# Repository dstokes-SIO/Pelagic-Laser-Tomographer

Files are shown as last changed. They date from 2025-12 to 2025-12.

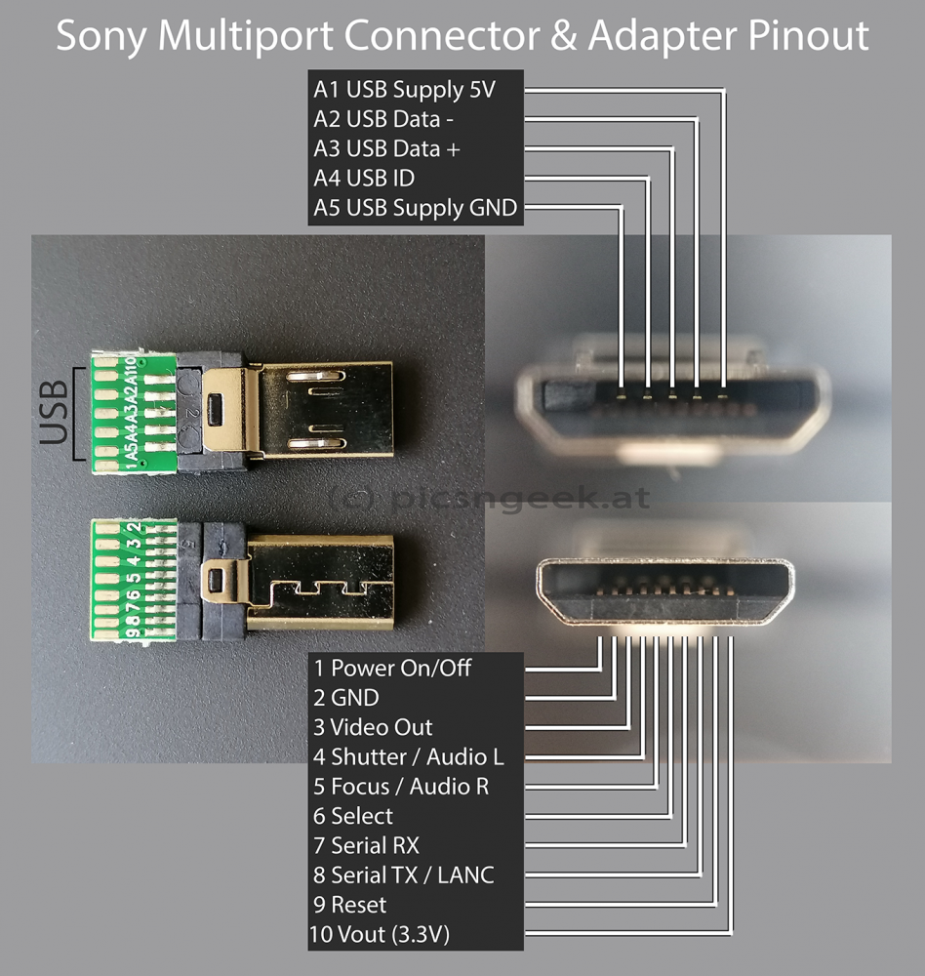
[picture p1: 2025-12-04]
Misc Hardware/Sony-Multiport-Connector-and-Adapter-Pinout-50.png

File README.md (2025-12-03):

[PLT_Processing_User_Guide.md](https://github.com/user-attachments/files/23918088/PLT_Processing_User_Guide.md)
# **PLT Processing User Guide**

## **1. Introduction**

This document describes the processing workflow for the Pelagic Laser Tomographer (PLT) dataset.  
The goal of the pipeline is to convert raw Sony ARW image sequences and associated depth logs into cleaned, standardized **dot table CSV files** for each drop.

The PLT processing pipeline is modular and consists of the following components:

- **Raw data (ARW images + CSV log)**
- **GenerateRunDrops.py** — identifies drops and organizes input files
- **RunPLTFilter.py** — stages images, runs the C++ `pltfilter` algorithm, and produces output dot files
- **Concatenate outputs** — produces `AllDots.csv` for each drop

This guide explains how to run each stage, the required directory structure, and how to interpret the resulting files.

---

## **2. Processing Pipeline Overview**

The system processes a PLT “run” (e.g., `data_50`) consisting of:

- A raw CSV log file: `data_50.csv` generated during PLT operations
- A set of raw ARW images containing several drops (drops = depth cast of PLT from winch or hand held)

The processing steps are:

1. **GenerateRunDrops.py**
   - Reads the raw images
   - Reads the raw log
   - Detects drops and isolates them
   - Produces:
     - One folder per drop
     - `images_fullpath.txt`
     - `drop_metadata.yaml`

2. **RunPLTFilter.py**
   - Reads each drop folder
   - Symlinks all images for the drop into a sequentially numbered directory
   - Cleans the log file (standardizes depth column name)
   - Constructs a `pltfilter` command based on `plt_config.yaml`
   - Calls the C++ `pltfilter` binary
   - Produces:
     - `DotsPerImage/*.dots.csv`
     - Summary histogram files
     - `AllDots.csv`

3. **Downstream analysis** (not covered here)
   - Users may apply their own scripts for density, depth structure, or cross-drop comparison.

---

## **3. Directory Structure**

A typical PLT working directory is organized as follows:

```
PLT/
  plt_config.yaml
  GenerateRunDrops.py
  RunPLTFilter.py
  PLTfilter/
    src/pltfilter
    RunTemplate/Mask.tiff
  drops/
    data_50/
      Drop01/
        images_fullpath.txt
        drop_metadata.yaml
        DropImages/
        Results/
  raw_data_05262023/
    data_50.csv
    ARW image folders
```

Key directories:

- **PLTfilter/**  
  Contains the compiled `pltfilter` executable and mask file.

- **drops/**  
  Contains per-run and per-drop processing outputs.

- **raw_data/**  
  Contains raw ARW image sets and raw log files.

---

## **4. Configuration File: `plt_config.yaml`**

All path definitions and `pltfilter` parameters live in `plt_config.yaml`.  
Important sections are:

### **4.1 paths**
```yaml
paths:
  drop_root: "/path/to/PLT/drops"
  data_file: "/path/to/raw_data/data_50.csv"
  raw_images_root: "/path/to/raw_images"
```

- `drop_root`: Parent folder under which drop folders will be created  
- `data_file`: Raw CSV log for the run  
- `raw_images_root`: Root folder containing ARW images

### **4.2 pltfilter**
Defines how `RunPLTFilter.py` constructs the C++ `pltfilter` command.

Key fields:

```yaml
pltfilter:
  binary: "/path/to/PLTfilter/src/pltfilter"
  mask_file: "/path/to/Mask.tiff"
  median_window: 3
  adaptive_threshold_window: 31
  adaptive_threshold_bias: -9
  dilation_count: 1
  min_dot_radius: 1
  max_dot_radius: 10
  min_dot_area: 1
  max_dot_area: 100
  false_z_spacing: 25.0
  pixels_per_cm: 77.165
  depth_histogram_bucket_width: 0.1
  save_dots: true
```

---

## **5. Running the Pipeline**

### **5.1 Step 1 — Prepare Raw Data**

Ensure that:

- The raw CSV log (e.g., `data_50.csv`) is located where `plt_config.yaml` points.
- ARW image folders are accessible.
- The directory structure is consistent with `GenerateRunDrops.py`.

No additional formatting of raw logs is required.

---

### **5.2 Step 2 — Identify Drops**

To process a run (e.g., run number 50):

```python
runfile("GenerateRunDrops.py", args="50", wdir="...")
```

This script:

- Reads the raw ARW images & timestamps
- Selects frames belonging to each drop
- Creates a directory for each drop:

```
drops/data_50/Drop01
drops/data_50/Drop02
...
```

Each drop folder contains:

- `images_fullpath.txt` — list of ARW file paths  
- `drop_metadata.yaml` — includes:
  - `drop_id`
  - `data_file`
  - `start_idx` (first log row for this drop)

This stage must be run before filtering.

---

### **5.3 Step 3 — Run PLT Filter**

To process all drops in a run:

```python
runfile("RunPLTFilter.py", args="50", wdir="...")
```

The script performs:

1. **Log cleaning**
   - Standardizes the “depth” column name so the C++ code recognizes it.

2. **Symlink image staging**
   - All ARW files for the drop are placed into:

     ```
     DropImages/Drop01_data_50/
       PLT000001.ARW
       PLT000002.ARW
       ...
     ```

3. **Calls the C++ `pltfilter` binary**
   - Uses parameters from the YAML file
   - Writes output to:

     ```
     Results/
       DotsPerImage/
       AllDots.csv
       DotsRadiusHistogram.csv
       DotsAreaHistogram.csv
       DotsDepthHistogram.csv
     ```

Progress and command-line details print to the console.

---

### **5.4 Step 4 — Inspect Output**

Inside each drop’s `Results/` folder:

#### **AllDots.csv**
Combined dot detections for all frames in the drop.  
Columns include:

- X-Pixels  
- Y-Pixels  
- Area  
- Radius  
- Frame number  
- Depth (if logged)

#### **DotsPerImage/**
Individual dot detections per frame.

#### **Histogram files**
Summaries of:

- Dot radii  
- Dot areas  
- Dot depth distribution

---

## **6. Troubleshooting**

### **6.1 pltfilter: column not found: Depth**
Cause: Raw log contains nonstandard column header (e.g., `depth (m)` or `Depth (m)`).

Solution:  
`RunPLTFilter.py` automatically cleans logs.  
Check for:

```
output/data_XX_clean_for_pltfilter.csv
```

Make sure the cleaned file contains a column named exactly:

```
Depth
```

---

### **6.2 pltfilter not found**
Ensure the YAML contains:

```yaml
pltfilter:
  binary: "/Users/.../PLTfilter/src/pltfilter"
```

---

### **6.3 Missing Mask.tiff**
Verify:

```yaml
mask_file: "/Users/.../PLTfilter/RunTemplate/Mask.tiff"
```

---

### **6.4 No DotsPerImage files generated**
Possible causes:

- Mask cropping out entire frame  
- Wrong threshold settings  
- Bad exposure or blank images

Try lowering threshold bias or disabling adaptive thresholding.

---

### **6.5 ARW files not found**
Check the content of:

```
drops/data_XX/DropNN/images_fullpath.txt
```

Paths must be absolute or resolvable.

---

## **7. Notes on Extending the Pipeline**

Advanced users may wish to:

- Adjust detection thresholds in YAML  
- Add new metadata fields  
- Replace `pltfilter` with a GPU version  
- Implement Python-based dot detectors  
- Export PLT dot clouds to MATLAB or NumPy arrays  
- Add automatic QA/QC after filtering  

This guide covers only the canonical workflow.

---

## **8. Summary**

This user guide provides the minimal, operational recipe for running the full PLT processing pipeline:

1. Configure paths in `plt_config.yaml`  
2. Generate drop folders using `GenerateRunDrops.py`  
3. Run filtering using `RunPLTFilter.py`  
4. Inspect `Results/AllDots.csv` and summary files

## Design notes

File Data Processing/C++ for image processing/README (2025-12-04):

src
The “src” directory has the PLT filter’s C++ code. These are the files:
	crop.cpp        - crop images to the relevant area
	gray.cpp        - convert images to grayscale
	histogram.cpp   - generate a histogram
	median.cpp      - do a median filter of images
	pltfilter.cpp   - find dots and produce a CSV result
	threshold.cpp   - threshold images
	rapidcsv.h      - the CVS parser from above

“pltfilter” is the main program. It reads in a single image or a directory of images and…
	1	Converts each image to grayscale using the green channel alone.
	2	Optionally applies a median filter to remove small-scale noise.
	3	Optional thresholds to drop out dim features and brighten the rest.
	4	Optional masks the image against an image mask to remove device parts in the camera’s view.
	5	Contours the resulting image to find dots.
	6	Filters out dots that are too big or small to be reasonable.

The other source files are optional separate tools used to do just one processing step and see the results. They are useful for debugging, but are not needed for dot generation.

Installing libraries
The tools, including primarily “pltfilter”, require two libraries:
	libraw   - read RAW images, like from the PLT camera
	opencv4  - do image processing and contours

Both libraries must be installed on your Mac. If you use MacPorts (recommended), you can download and install these, and their dependencies, with these two commands in a shell window:
	port install libraw
	port install opencv4 +nonfree +contrib +openmp

MacPorts will handle getting compilers, etc, so that these build.

You specifically need the OpenMP version of OpenCV. This is used to parallelize image processing across your Mac’s cores so that everything runs faster.

These are what I used last in 2021. There may be newer versions or complexities.

Building PLT filter
Use a shell window and go to the “src” directory and type:
	make pltfilter

When you make “pltfilter”, the application will be compiled into a binary named “pltfilter” in the same directory. While you can run it from a shell window, it has a large number of arguments that must be set appropriately. This is handled with shell scripts (see below).

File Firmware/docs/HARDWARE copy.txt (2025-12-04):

HARDWARE
------------------------------------------------------------------------

The PLT Logger requires the following hardware:

- An Adafruit Feather M0 arduino microcontroller. The device has 32k of
  RAM, 262k of flash memory, an SD card controller, red and green status
  LEDs, and a series of pins used to access additional devices.

- An LSM9DS1 9-axis iNEMO inertial module (IMU). The sensor incorporates
  a 3D magnetometer, 3D accelerometer, and 3D gyroscope. The module also
  reports the internal device temperature.

- A MS5837 30 bar digital pressure sensor. The sensor reports water
  pressure and depth to a 2mm resolution. An included low-resolution
  water temperature sensor is not used.

- A TSYS01 digital temperature sensor. The high-resolution sensor reports
  water temperature between -5 and 50 C, +/- 0.1C.

- Three NEOPIX signle-wire-based multi-color LEDs. The LEDs are visible
  outside of the PLT pressure case and indicate device status and activity.

- An Adafruit DS3231 precision real-time clock. The clock provides a
  persistent date/time (with battery backup) and accurate timestamps used
  in log files.

- Two Adafruit LC709203F battery level monitors for the main and
  microcontroller battery. Each monitor provides battery voltage and an
  estimate of the charge level.

- An Adafruit TCA9548A 1-to-8 I2C bus multiplexor to support two battery
  level monitors.

See LIBRARIES.txt for a list of software libraries to use these components.

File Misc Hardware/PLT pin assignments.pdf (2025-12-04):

#pragma once

/**
* @file
* Define the microcontroller's pin usage.
*/

// Digital pins.
#define SDCARD_PIN | 4 | // SD memory card chip select

#define LSM9DS1_MCS_PIN | 5 | // Inertia module.

#define LSM9DS1_XGCS_PIN | 6 | // Inertia module.

#define BOARD_GREEN_LED_PIN | 8 | // Built-in board green LED

#define CAMERA_SHUTTER_PIN | 10 // Camera shutter relay

#define LASER_PIN | 11 // Laser on/off relay

#define LSM9DS1_MISO_PIN | 12 // Inertia module.

#define BOARD_RED_LED_PIN | 13 // Built-in board red LED

#define STARTSTOP_SWITCH_PIN | 14 // Start/stop switch

#define CAMERA_POWER_SET_PIN | 15 // Camera power relay set

#define INTENSIFIER_POWER_SET_PIN | 17 // Intensifier power relay set

#define INTENSIFIER_POWER_UNSET_PIN 18 // Intensifier power relay unset

#define NEOPIXELS_PIN | 19 // Multi-colored LED group

// Analog pins.
#define LSM9DS1_MOSI_PIN | A4 // Inertia module.

#define LSM9DS1_SCK_PIN | A5 // Inertia module.

// Only used if battery monitoring uses raw voltage. See Battery.h and
// BATTERY_USE_RAW_VOLTAGE for BATTERY_ENABLE_CONTROLLER_MONITORING and
// BATTERY_ENABLE_MAIN_MONITORING.
#define CONTROLLER_BATTERY_VOLTAGE_PIN A7 // Controller battery raw voltage. #define MAIN_BATTERY_VOLTAGE_PIN A7 // Main battery raw voltage.

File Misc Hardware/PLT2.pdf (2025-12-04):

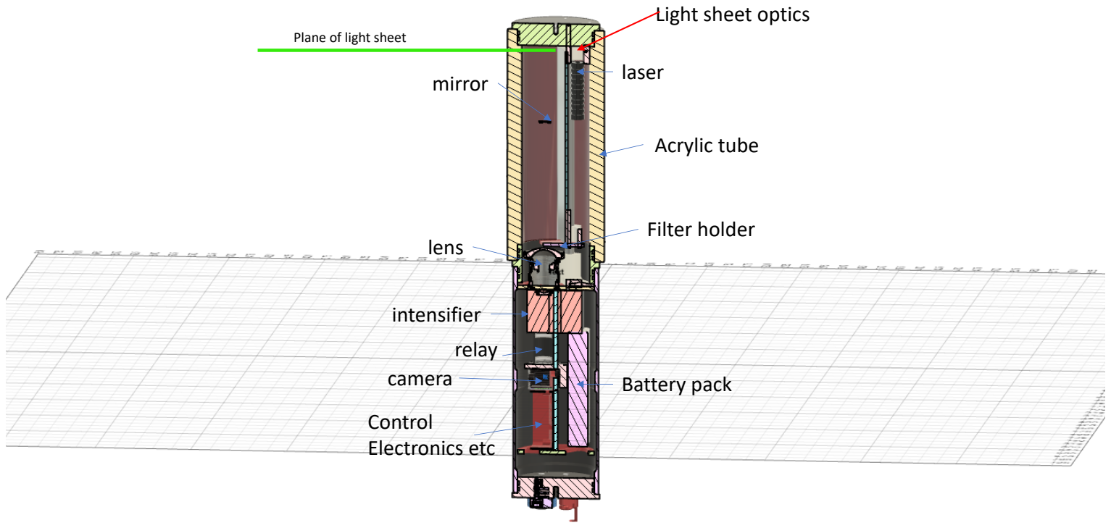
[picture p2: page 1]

camera

relay

intensifier

Battery pack
Control
Electronics etc

laser mirror

lens

Filter holder

Acrylic tube

Light sheet optics
Plane of light sheet

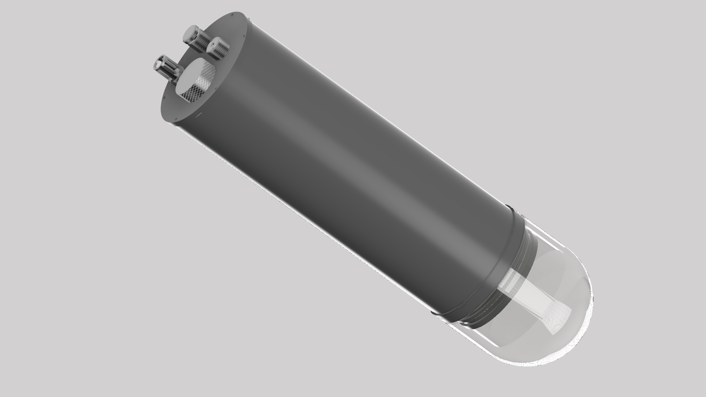
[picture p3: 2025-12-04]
Misc Hardware/PLT RX0ii Housing v1.png

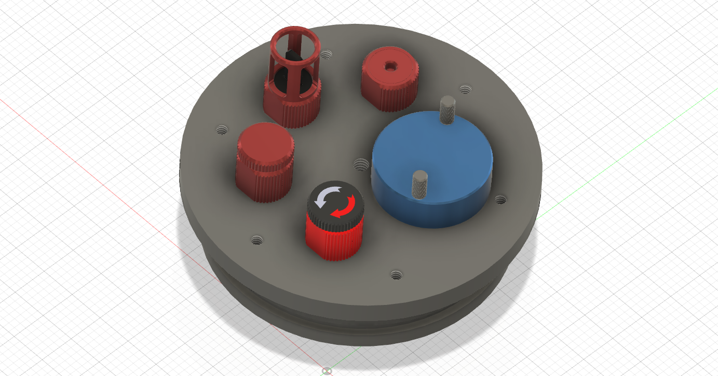
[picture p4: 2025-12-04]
Misc Hardware/new top cap with new orings v25 top.png

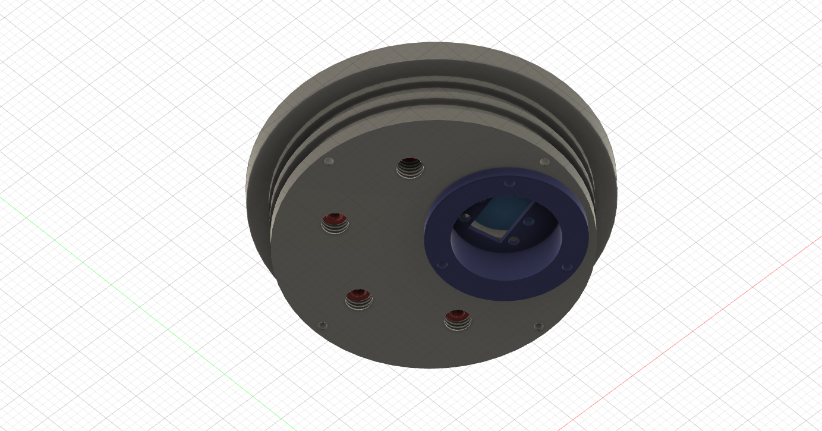
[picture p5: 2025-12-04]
Misc Hardware/new top cap with new orings v25 bottom.png

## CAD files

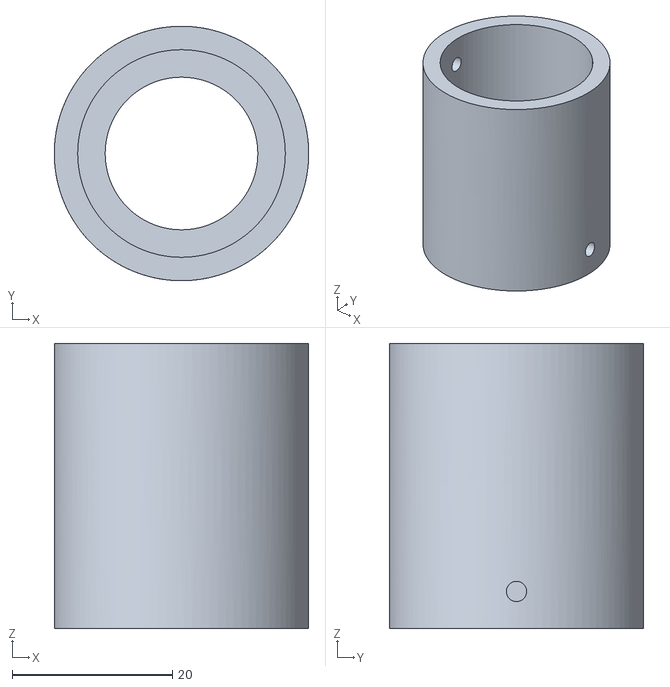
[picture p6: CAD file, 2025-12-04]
Misc Hardware/axixonmt v2.stl
31.8 x 31.7 x 35.6

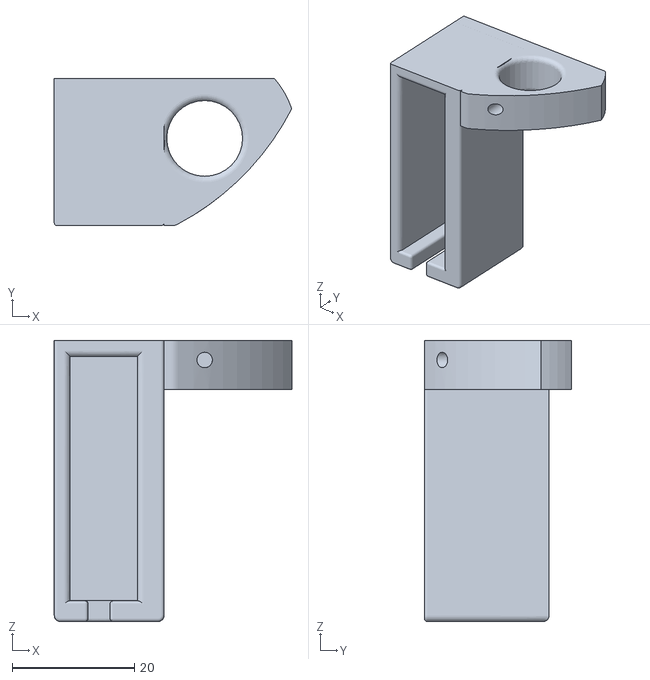
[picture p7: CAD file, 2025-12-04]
Misc Hardware/neo_refit.stl
38.9 x 24.1 x 46.0

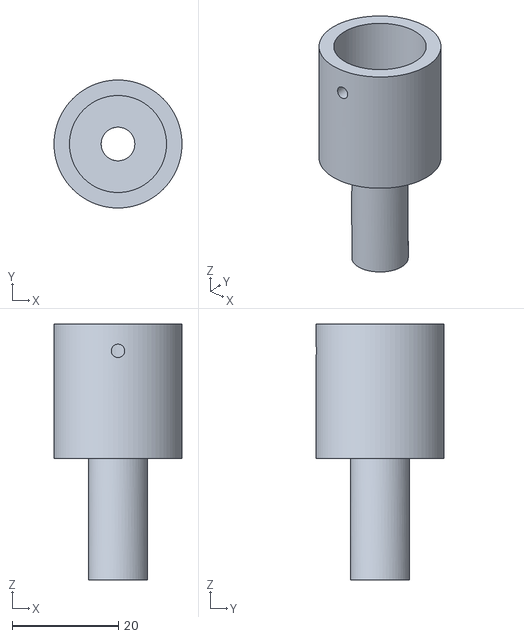
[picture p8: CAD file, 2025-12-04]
Misc Hardware/50mw green laser coupler v2.stl
24.1 x 24.1 x 48.3

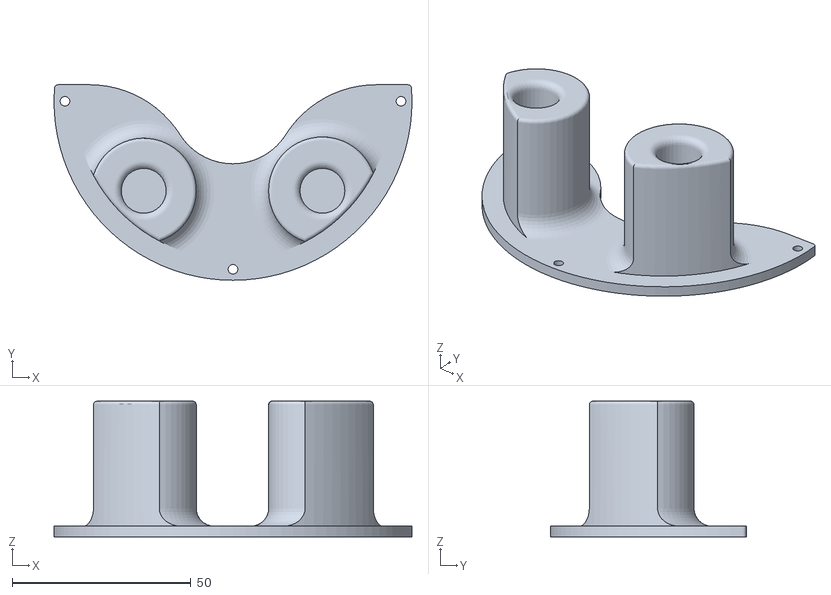
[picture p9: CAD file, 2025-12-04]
Misc Hardware/rodholdv14.stl
100.2 x 54.7 x 38.0

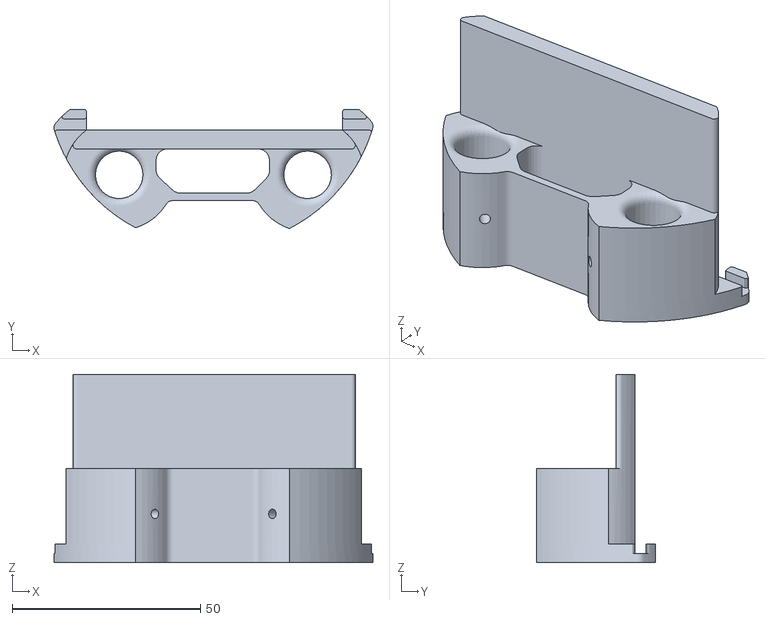
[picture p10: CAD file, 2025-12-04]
Misc Hardware/carriagev8.stl
84.7 x 31.6 x 50.0

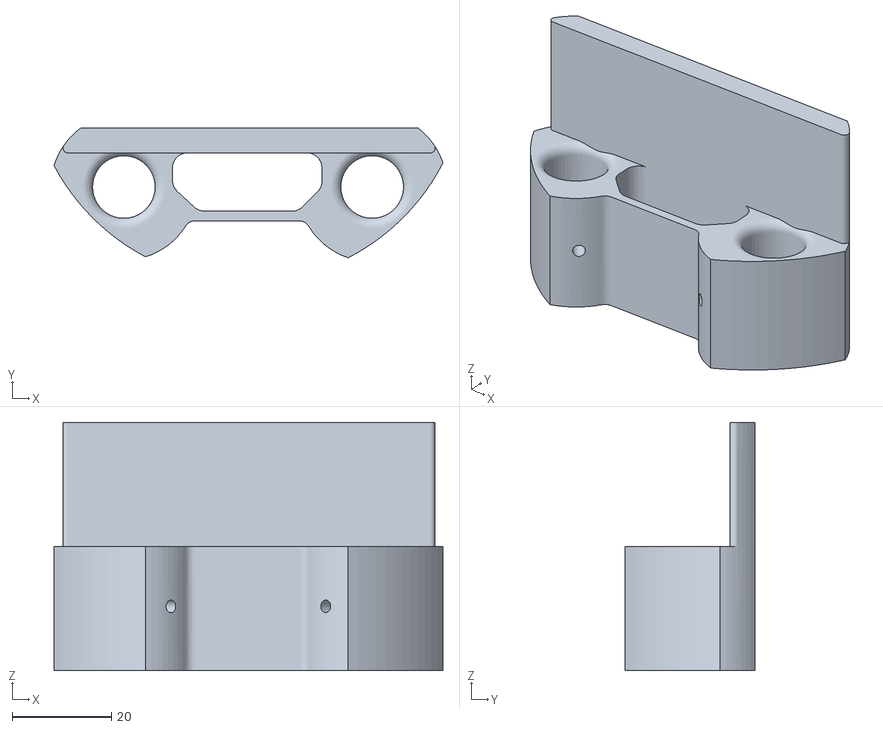
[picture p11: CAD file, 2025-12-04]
Misc Hardware/mirrhold.stl
78.3 x 26.1 x 50.0

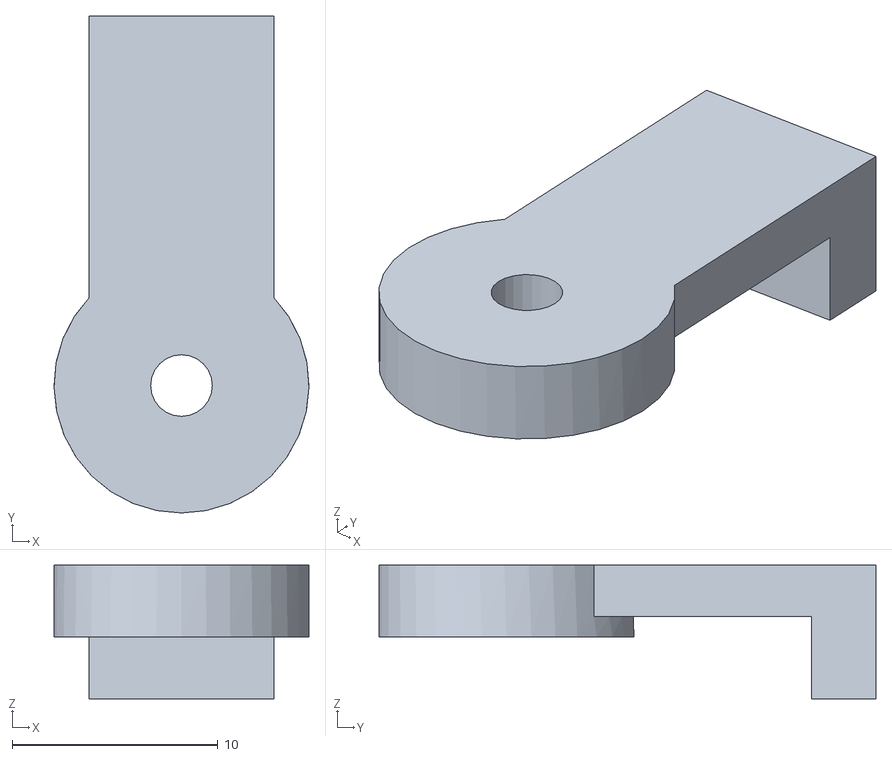
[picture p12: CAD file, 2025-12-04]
Misc Hardware/clampv13.stl
12.4 x 24.2 x 6.50

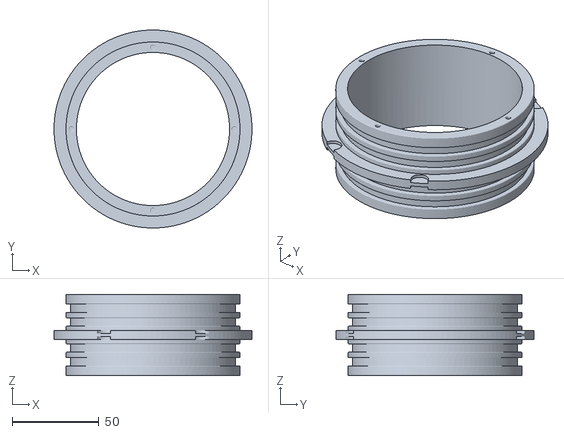
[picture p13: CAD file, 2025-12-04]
Misc Hardware/modified double WT4 flange v3.stl
114.3 x 114.2 x 47.0

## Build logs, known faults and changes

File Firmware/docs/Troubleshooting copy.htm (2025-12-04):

# PLT Troubleshooting

## Indicator lights

The device includes four indicator lights exposed at the top of the pressure case:

1. Power (off or green).
2. Hardware status (multi-colored).
3. Software status (multi-colored).
4. Camera status (multi-colored).

The status lights are only a broad indicator. For detailed information, use the USB interface and type "hwinfo" to review the hardware status.

Lights | Meaning
| Device is off.
| Device is on and loading the controller (< 1 sec).
| Device is booting (about 5 sec). Booting includes a fast sweep of the lights and the laser.
| Critical hardware problems. Possible causes: The controller battery is too low for use. The main battery is missing, dead, or too low for use. The SD card is not present. The SD card is not in FAT16, FAT32, or exFAT format. The SD card reader is not working or is misswired.
| Critical software problems. Possible causes: The SD card is full. The SD card has the maximum of 100 log files.
| Non-critical hardware problems that may prevent the device from running properly. Possible causes: The controller battery is low. The main battery is low. The real time clock is not working or is misswired. The real time clock battery is dead. The inertia module is not working or is misswired. The pressure sensor is not working or is misswired. The temperature sensor is not working or is misswired. The SD card is getting full.
| Device is ready.
| Device is booting the camera at the start of imaging.
| Device is imaging and waiting to take the next image. Camera and intensifier are on. Laser is on if in continuous mode.
| Device is imaging and the camera is taking an image (< 1/2 sec). Camera, intensifier, and laser are on.

## Boot messages

Device boot can show the following messages.

"Cannot run due to critical problems."

Critical hardware problems prevent the device from operating. See the hardware information shown during boot or type the USB "hwinfo" command for details.

"Ready for limited use despite problems."

Non-critical hardware problems may prevent the device from operating properly. See the hardware information shown during boot or type the USB "hwinfo" command for details.

"The real time clock was not found. Dates are 1/1/2000 + ms since boot."

The real time clock module was not found on boot. Dates all January 1st, 2000 plus the time since boot.

"Ready."

There were no boot problems and the device is ready.

## Hardware information (hwinfo) messages

The USB "hwinfo" command reviews the hardware status and can show the following messages.

"Missing SD card or bad card format"

The SD card file system handler could not be initialized. The SD card may not be present, the reader may not be working, or the card format may not be in FAT16, FAT32, or exFAT format.

"Unsupported SD card format"

The SD card file system handler could not be initialized. The SD card is using a FAT format variant that is not supported. Use the "format" command to reformat.

"LC709203F main battery monitor not found"

The battery level monitor module for the main battery could not be initialized. The module may not be working.

"LC709203F controller battery monitor not found"

The battery level monitor module for the controller battery could not be initialized. The module may not be working.

"DS3231 real time clock not found"

The real time clock module could not be initialized. The module may not be working.

"LSM9DS1 inertia module not found"

The inertia module (magnetometer, accelerometer, magnetometer) could not be initialized. The module may not be working.

"MS5837 pressure sensor not found"

The pressure sensor module could not be initialized. The module may not be working.

"MS5837 temperature sensor not found"

The temperature sensor module could not be initialized. The module may not be working.

## Error messages

During use, USB commands may show the following error messages.

"Missing SD card or bad card format"

The SD card file system handler could not be initialized. The SD card may not be present, the reader may not be working, or the card format may not be in FAT16, FAT32, or exFAT format.

"Too many log files; 100 max."

Recording cannot be started because there are already 100 log files, named "DATA_00.CSV" through "DATA_99.CSV". Remove at least one to continue.

"SD card is full"

The SD card is full. Recording cannot continue because there is no space for new data log entries. Remove some files to continue.

"The real time clock was not found. Dates are 1/1/2000 + ms since boot."

The real time clock module was not found on boot. Dates all January 1st, 2000 plus the time since boot.

"Date cannot be set. Real time clock not found."

The real time clock module was not found on boot. Use of the USB "date" command to set the date fails.

"Cannot write to data log file."

The SD card is full. Recording cannot continue because there is no space for new data log entries. Remove some files to continue.

Additional messages report device status or may report problems with user input, such as a bad file system path for "ls" or "cat" commands.

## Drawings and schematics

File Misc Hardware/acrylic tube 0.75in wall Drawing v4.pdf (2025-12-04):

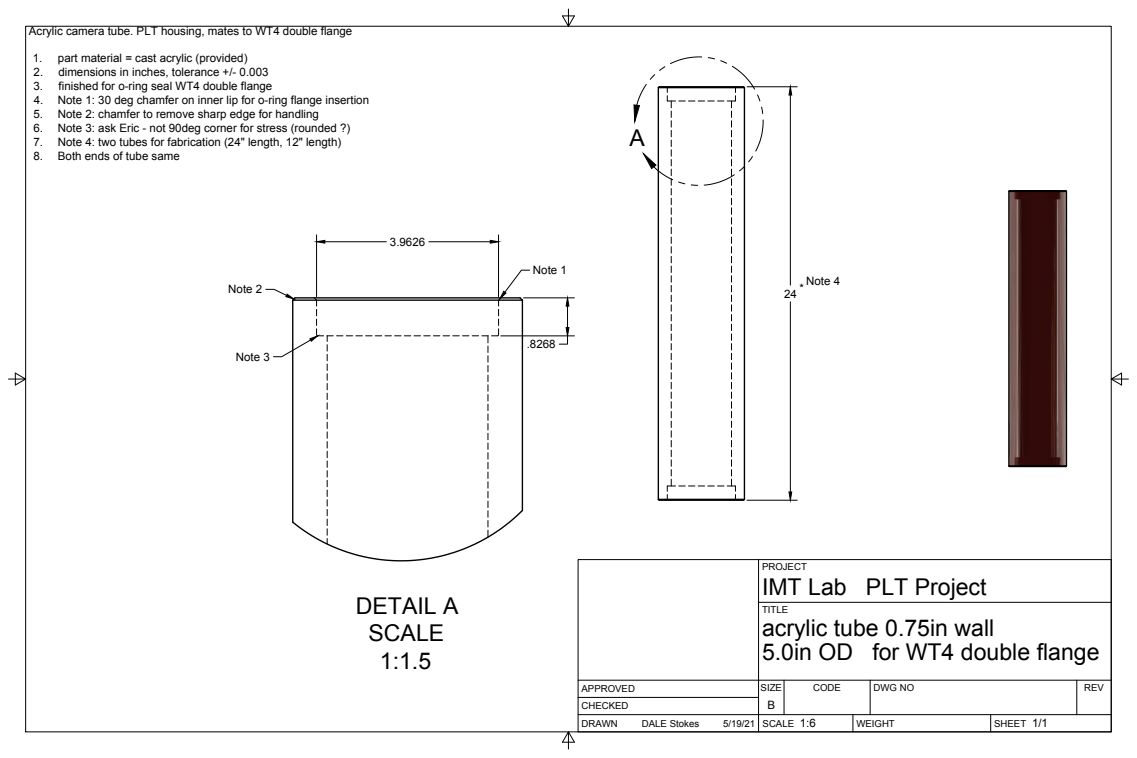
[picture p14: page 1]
SIZE; CODE; DWG NO; REV; DALE Stokes; Note 4 *; DETAIL A; Note 2; Note 3; Note 1

Acrylic camera tube. PLT housing, mates to WT4 double flange

1. part material = cast acrylic (provided)
2. dimensions in inches, tolerance +/- 0.003
3. finished for o-ring seal WT4 double flange
4. Note 1: 30 deg chamfer on inner lip for o-ring flange insertion
5. Note 2: chamfer to remove sharp edge for handling
6. Note 3: ask Eric - not 90deg corner for stress (rounded ?)
7. Note 4: two tubes for fabrication (24" length, 12" length)
8. Both ends of tube same

PROJECT
IMT Lab PLT Project
acrylic tube 0.75in wall
5.0in OD for WT4 double flange

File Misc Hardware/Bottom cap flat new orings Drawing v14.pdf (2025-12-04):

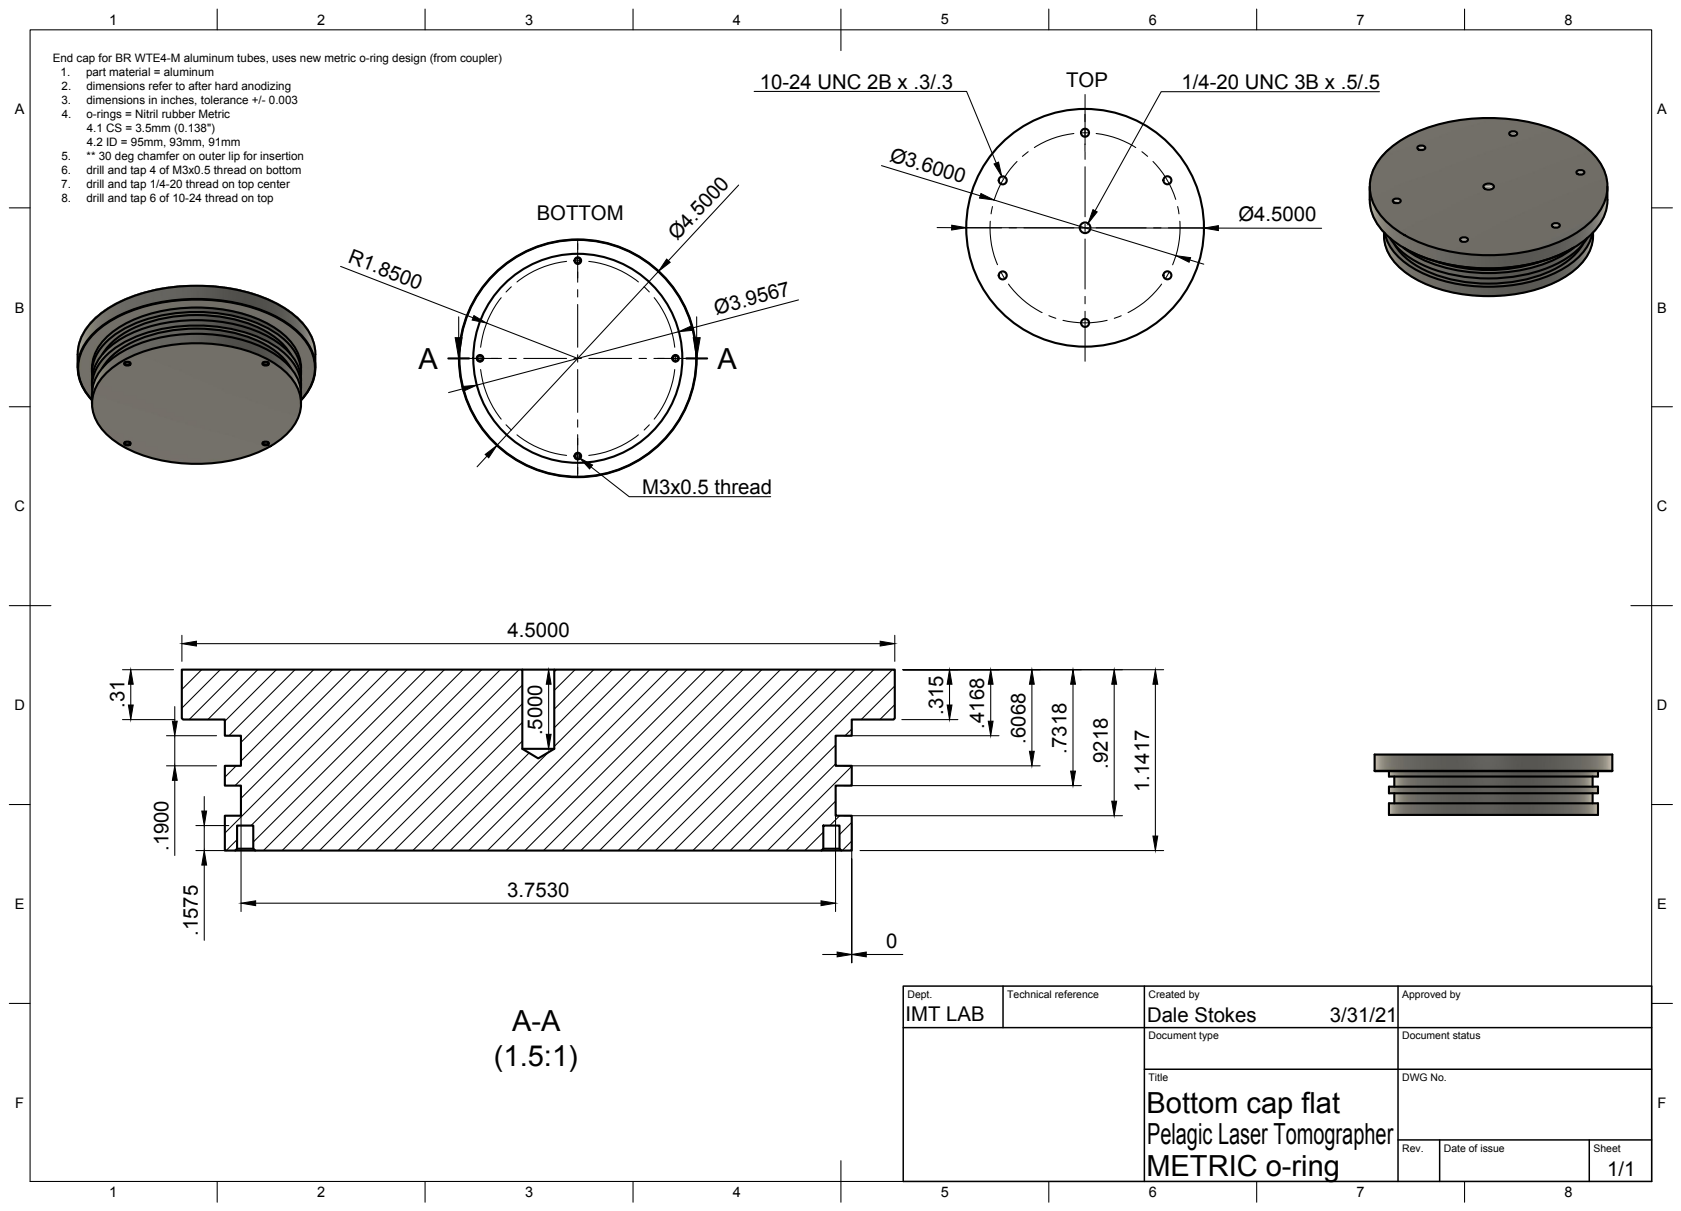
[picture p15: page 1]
Title; DWG No.; Rev.; Date of issue; Sheet; 1/4-20 UNC 3B x .5/.5; M3x0.5 thread; 10-24 UNC 2B x .3/.3

End cap for BR WTE4-M aluminum tubes, uses new metric o-ring design (from coupler)
1. part material = aluminum
2. dimensions refer to after hard anodizing
3. dimensions in inches, tolerance +/- 0.003
4. o-rings = Nitril rubber Metric
5. ** 30 deg chamfer on outer lip for insertion
6. drill and tap 4 of M3x0.5 thread on bottom
7. drill and tap 1/4-20 thread on top center
8. drill and tap 6 of 10-24 thread on top

Dept. IMT LAB | Technical reference | Created by Dale Stokes 3/31/21 | Approved by

Document type | Document status

Bottom cap flat
Pelagic Laser Tomographer
METRIC o-ring

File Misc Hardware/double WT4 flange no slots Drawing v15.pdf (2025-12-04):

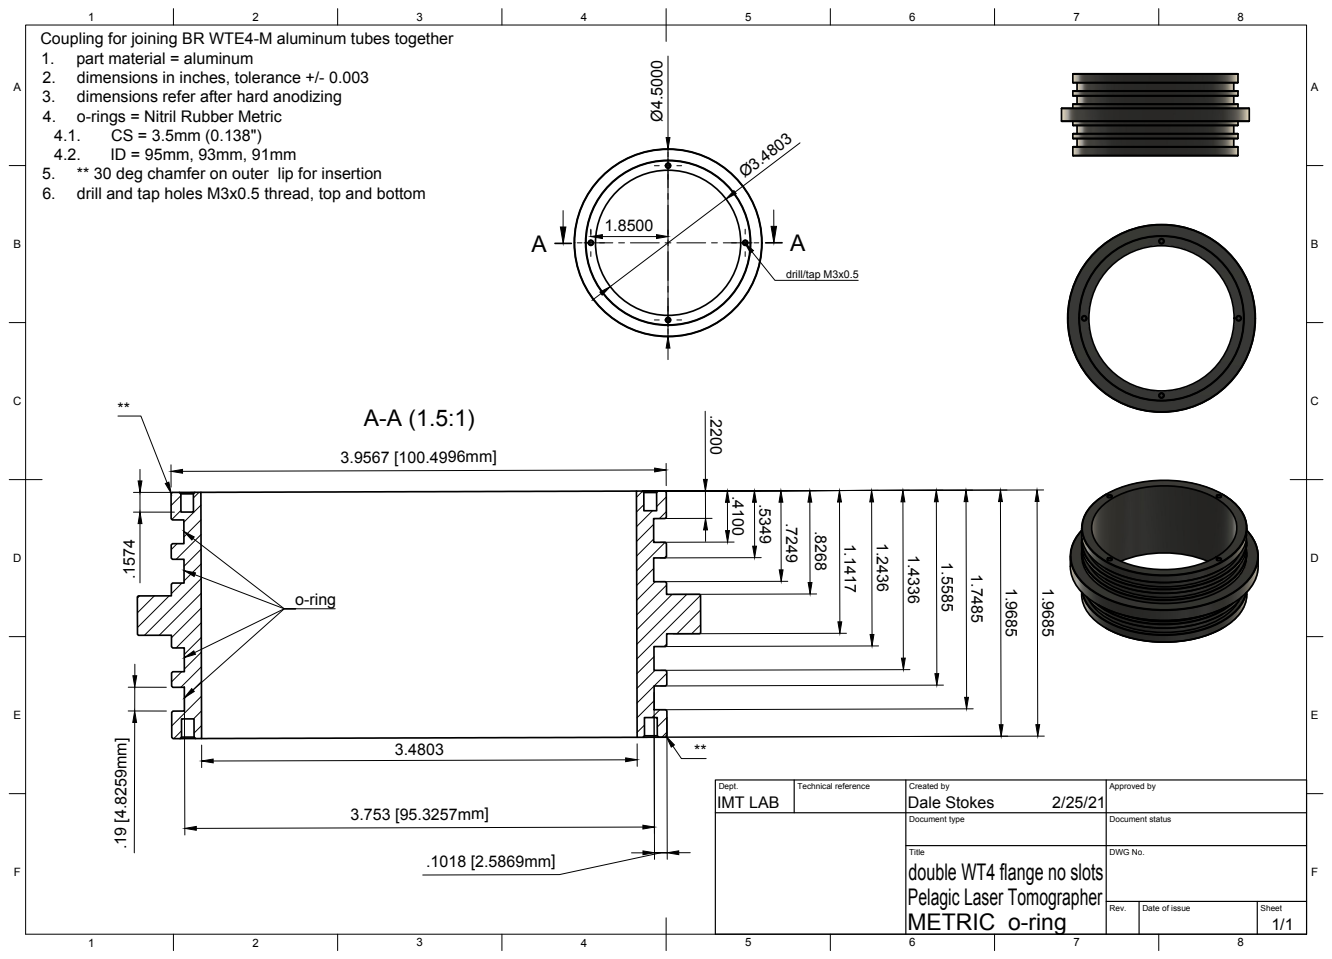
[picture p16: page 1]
Title; DWG No.; Rev.; Date of issue; Sheet; drill/tap M3x0.5; 1.9685 o-ring

Coupling for joining BR WTE4-M aluminum tubes together
1. part material = aluminum
2. dimensions in inches, tolerance +/- 0.003
3. dimensions refer after hard anodizing
4. o-rings = Nitril Rubber Metric
5. ** 30 deg chamfer on outer lip for insertion
6. drill and tap holes M3x0.5 thread, top and bottom

Dept. IMT LAB | Technical reference | Created by Dale Stokes 2/25/21 | Approved by

Document type | Document status

double WT4 flange no slots
Pelagic Laser Tomographer
METRIC o-ring

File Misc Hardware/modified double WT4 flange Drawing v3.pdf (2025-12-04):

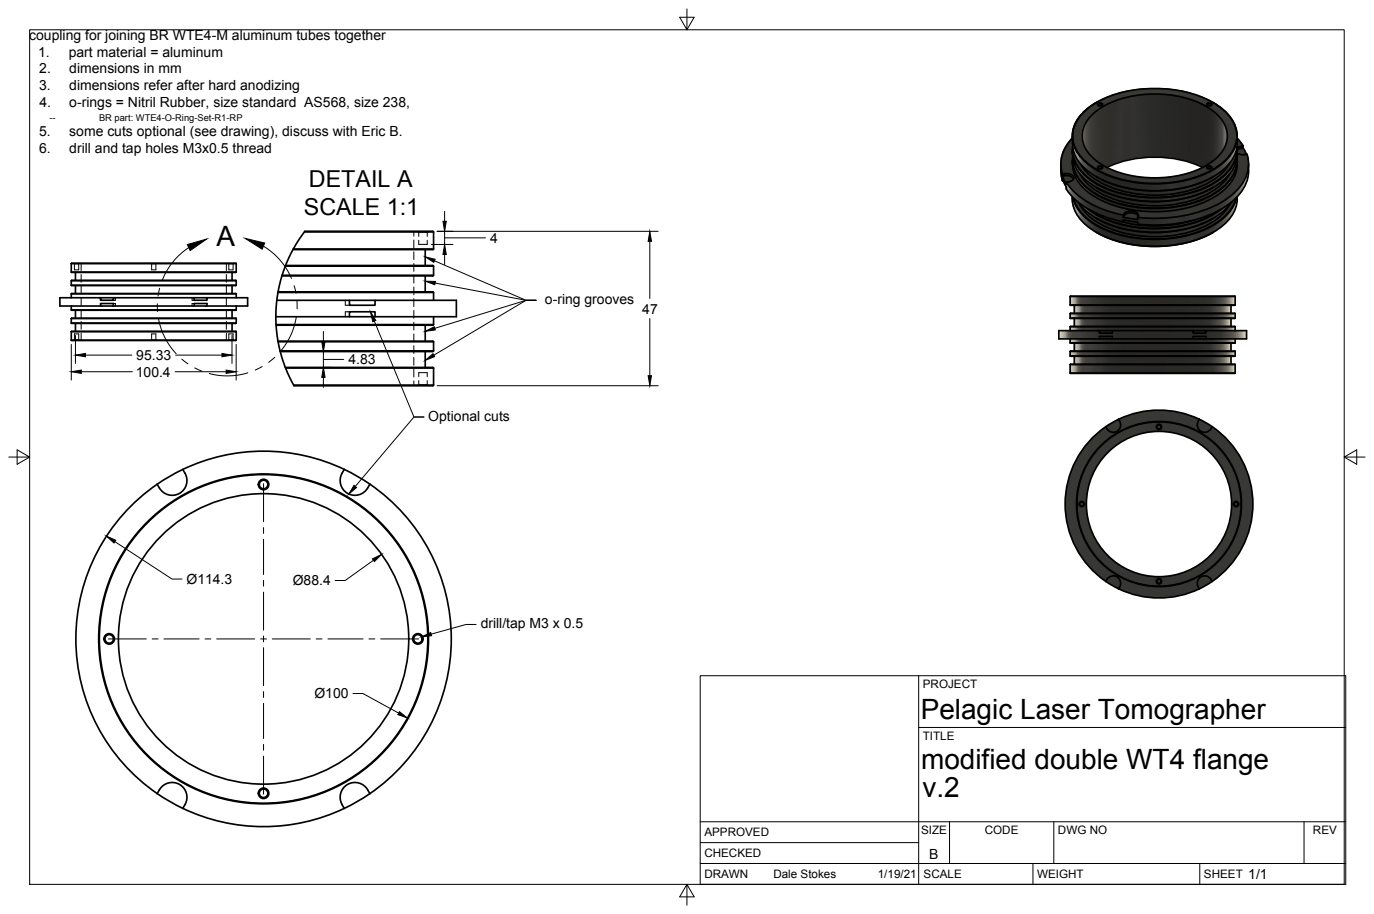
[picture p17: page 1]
SIZE; CODE; DWG NO; REV; Dale Stokes; BR part: WTE4-O-Ring-Set-R1-RP; DETAIL A SCALE 1:1; o-ring grooves; Optional cuts; drill/tap M3 x 0.5

coupling for joining BR WTE4-M aluminum tubes together
1. part material = aluminum
2. dimensions in mm
3. dimensions refer after hard anodizing
4. o-rings = Nitril Rubber, size standard AS568, size 238,

5. some cuts optional (see drawing), discuss with Eric B.
6. drill and tap holes M3x0.5 thread

PROJECT
Pelagic Laser Tomographer
modified double WT4 flange

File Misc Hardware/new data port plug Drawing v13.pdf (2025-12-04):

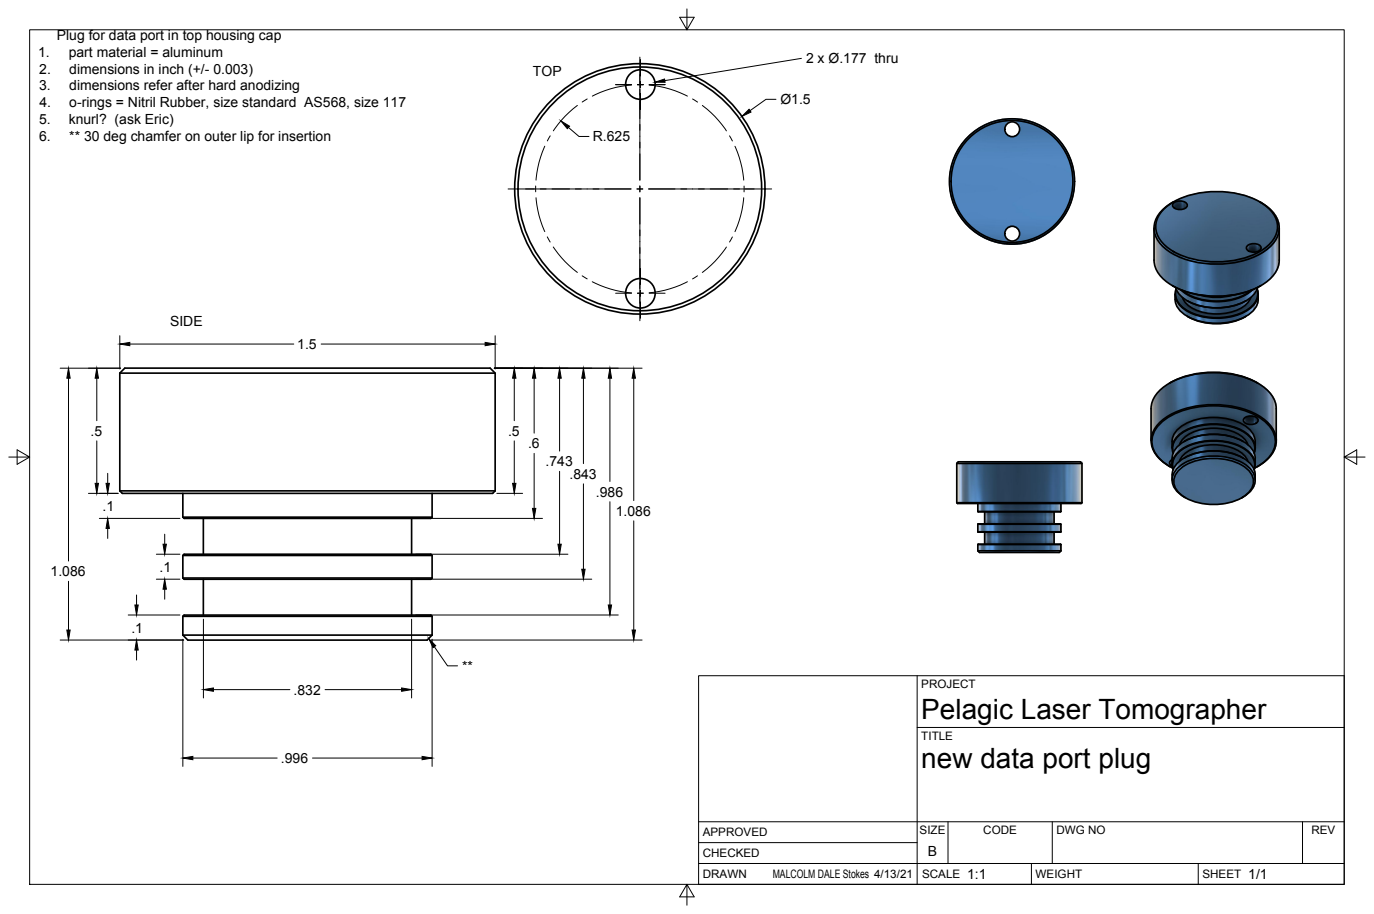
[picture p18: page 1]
SIZE; CODE; DWG NO; REV; MALCOLM DALE Stokes 4/13/21; 2 x Ø.177 thru

Plug for data port in top housing cap
1. part material = aluminum
2. dimensions in inch (+/- 0.003)
3. dimensions refer after hard anodizing
4. o-rings = Nitril Rubber, size standard AS568, size 117
5. knurl? (ask Eric)
6. ** 30 deg chamfer on outer lip for insertion

PROJECT
Pelagic Laser Tomographer
new data port plug

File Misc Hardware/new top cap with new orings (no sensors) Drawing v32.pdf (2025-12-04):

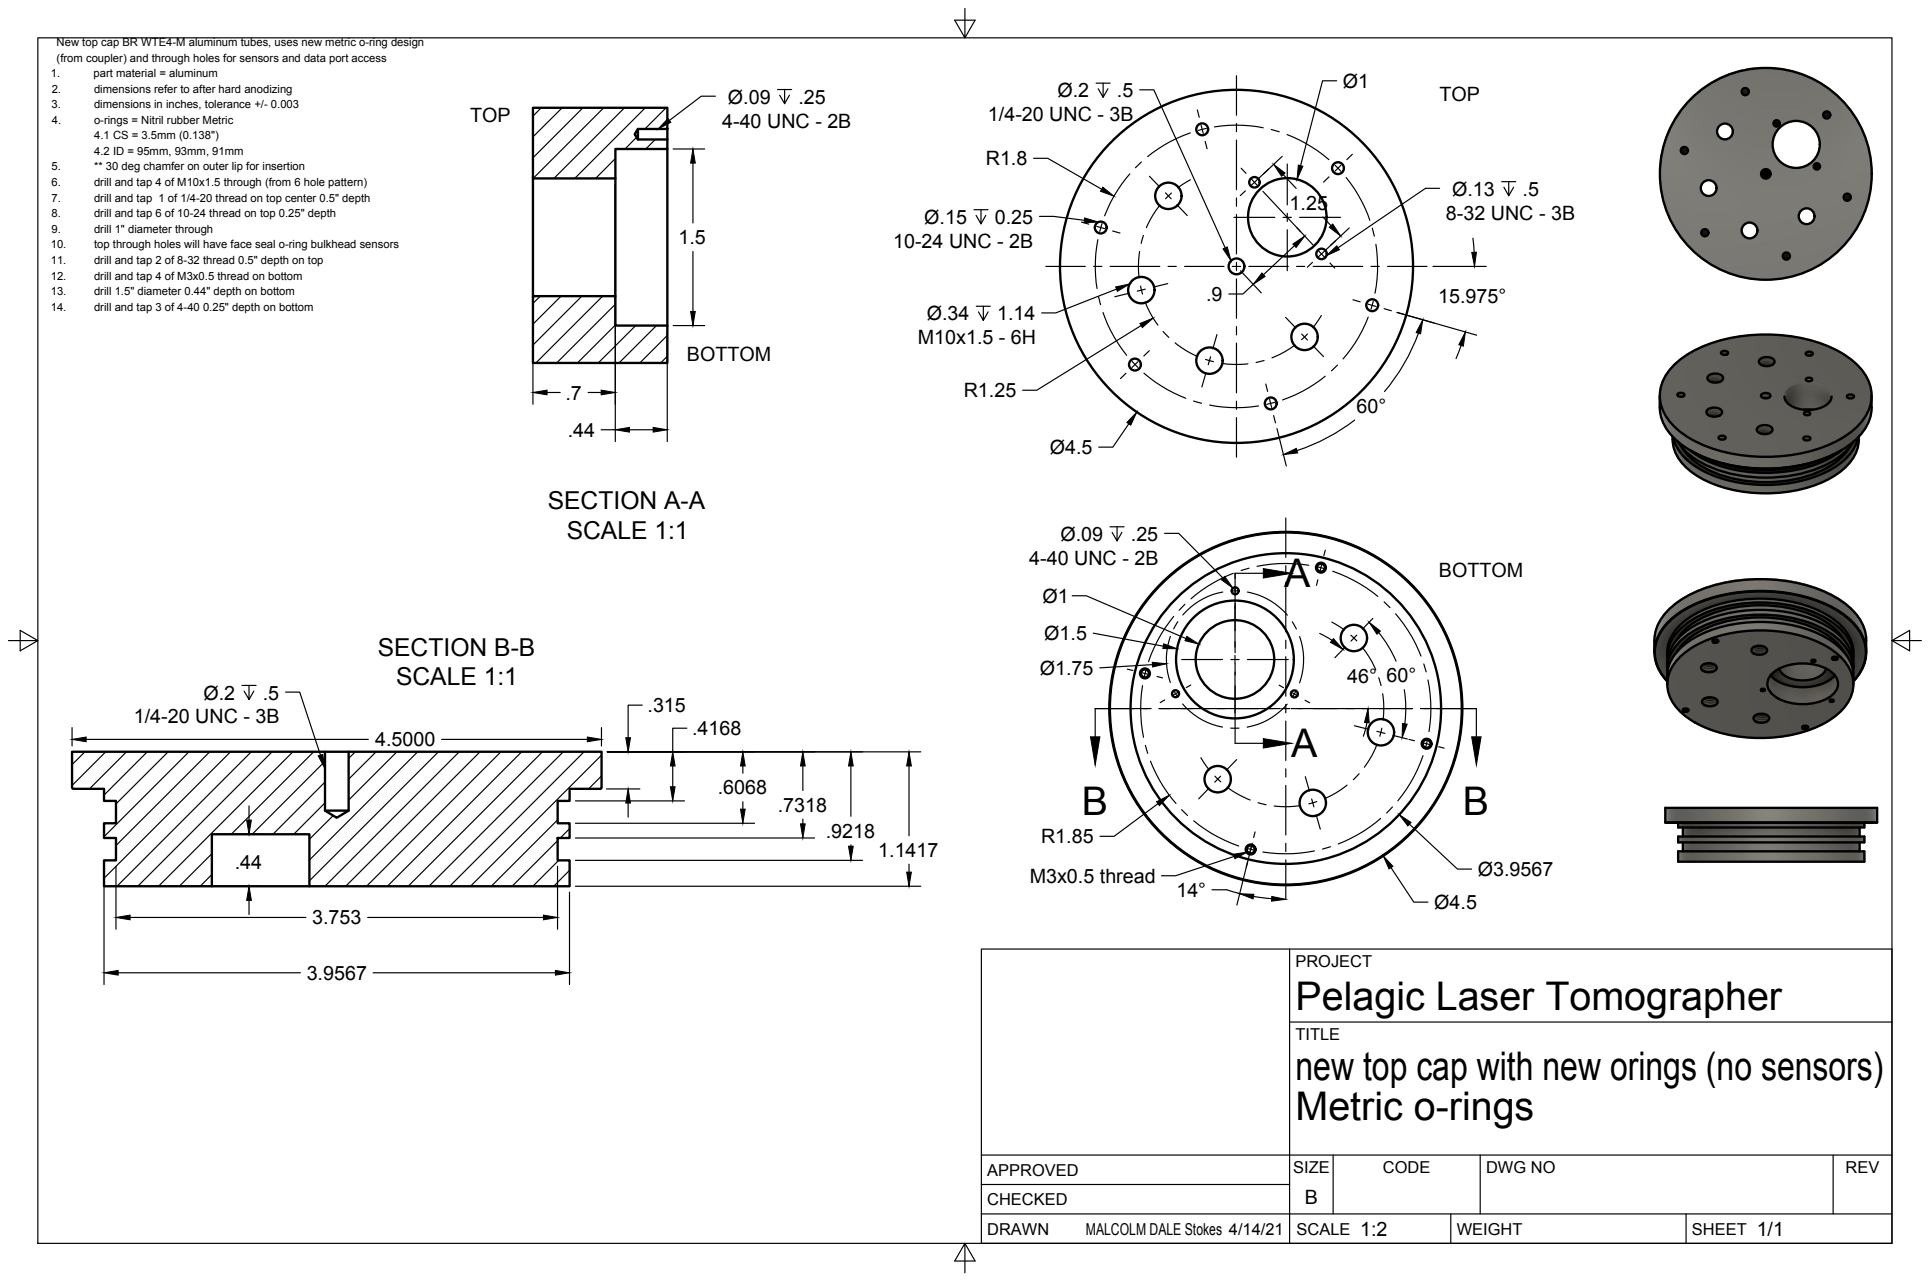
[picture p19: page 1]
SIZE; CODE; DWG NO; REV; MALCOLM DALE Stokes 4/14/21; 1/4-20 UNC - 3B; 10-24 UNC - 2B; 4-40 UNC - 2B; 8-32 UNC - 3B; M3x0.5 thread 14°; SECTION A-A SCALE 1:1; TOP; SECTION B-B; SCALE 1:1 Ø.2

New top cap BR WTE4-M aluminum tubes, uses new metric o-ring design
(from coupler) and through holes for sensors and data port access
1. part material = aluminum
2. dimensions refer to after hard anodizing
3. dimensions in inches, tolerance +/- 0.003
4. o-rings = Nitril rubber Metric

5. ** 30 deg chamfer on outer lip for insertion
6. drill and tap 4 of M10x1.5 through (from 6 hole pattern)
7. drill and tap 1 of 1/4-20 thread on top center 0.5" depth
8. drill and tap 6 of 10-24 thread on top 0.25" depth
9. drill 1" diameter through
10. top through holes will have face seal o-ring bulkhead sensors
11. drill and tap 2 of 8-32 thread 0.5" depth on top
12. drill and tap 4 of M3x0.5 thread on bottom
13. drill 1.5" diameter 0.44" depth on bottom
14. drill and tap 3 of 4-40 0.25" depth on bottom

PROJECT
Pelagic Laser Tomographer
new top cap with new orings (no sensors)
Metric o-rings

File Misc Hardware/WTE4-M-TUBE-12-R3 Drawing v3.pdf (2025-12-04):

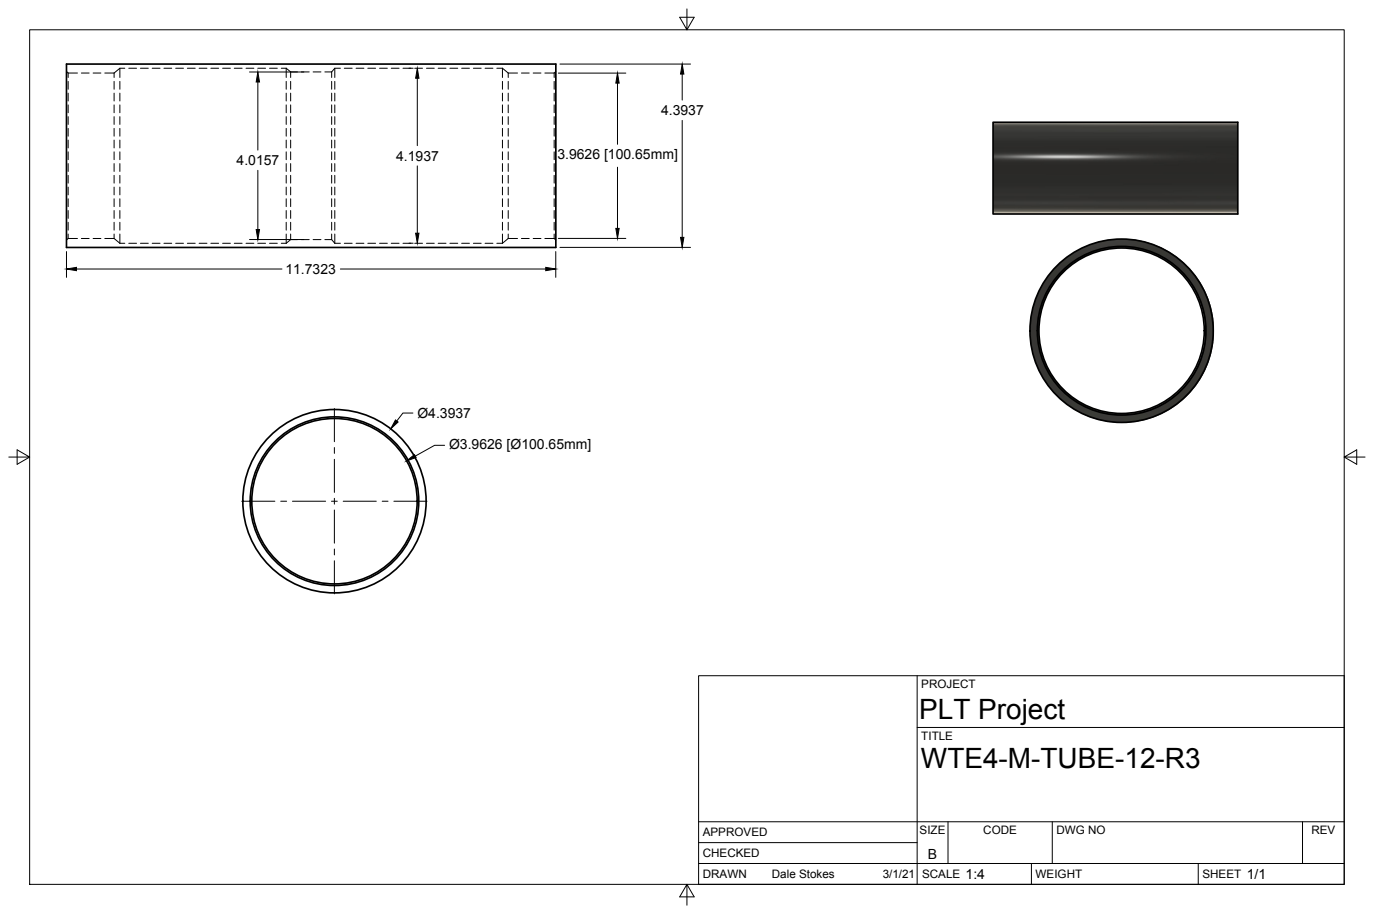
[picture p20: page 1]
SIZE; CODE; DWG NO; REV; Dale Stokes; PLT Project

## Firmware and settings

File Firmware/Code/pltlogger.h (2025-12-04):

#pragma once

#define VERSION "Sept 23, 2021"


//----------------------------------------------------------------------
// Debug features.
//----------------------------------------------------------------------
// Debug-only. Define to enable device boot to wait until the serial
// port is ready before continuing. If there is no computer attached to
// the USB port, this will cause the boot to hang. But if there is,
// then boot messages will be printed to the port and visible by a
// terminal monitor on the port. This can be useful during boot debugging.
//#define DEBUG_SERIAL

// Debug-only. Define to enable benchmarking during the snap-and-log
// process. This reports to the serial output the milliseconds taken
// for each major step in capturing an image, including turning on
// the laser, tripping the shutter, turning off the laser, and logging
// the results.
//#define DEBUG_BENCHMARK_SNAP_AND_LOG

// Debug-only. Define to enable messages to the serial output on each
// major camera action, such as power on/off and shutter.
//#define DEBUG_VERBOSE_CAMERA

// Debug-only. Define to enable messages to the serial output on each
// major laser action, such as power on/off.
//#define DEBUG_VERBOSE_LASER

// Debug-only. Define to enable messages to the serial output on each
// major battery action, such as initialization and checking levels.
//#define DEBUG_VERBOSE_BATTERY

// Debug-only. Define to enable messages to the serial output on each
// major clock action, such as initialization and setting values.
//#define DEBUG_VERBOSE_CLOCK

// Debug-only. Define to enable messages to the serial output on each
// major lights action, such as initialization and turning them on/off.
//#define DEBUG_VERBOSE_LIGHTS

// Debug-only. Define to enable messages to the serial output on each
// major sensors action, such as initialization and reading values.
//#define DEBUG_VERBOSE_SENSORS

// Debug-only. Define to enable messages to the serial output on each
// major switches action, such as initialization, press, and release.
//#define DEBUG_VERBOSE_SWITCHES

// Debug-only. Define to convert critical errors for missing batteries into
// warnings only. This should not be defined in production, but when debugging
// this allows the device to try to operate even when it cannot find its
// batteries.
#define DEBUG_BATTERY_MISSING_IS_WARNING

// Debug-only. Define to convert critical errors for missing sensors into
// warnings only. This should not be defined in production, but when debugging
// this allows the device to try t operate even when it cannot find its
// sensors.
#define DEBUG_SENSORS_MISSING_IS_WARNING

// Debug-only. Define to convert critical errors for missing clock into
// warnings only. This should not be defined in production, but when debugging
// this allows the device to try t operate even when it cannot find its
// clock.
#define DEBUG_CLOCK_MISSING_IS_WARNING


//----------------------------------------------------------------------
// Software features.
//----------------------------------------------------------------------
// Optional but recommended. Define to enable periodic battery level
// checks. When the battery level drops below a warning level (see
// BATTERY_WARN_PERCENT) the device sets the hardware state to a warning.
// When the level drops below the error level (see BATTERY_ERROR_PERCENT),
// the device sets the hardware state to a error and stops snap-and-log. The
// periodic check (see BATTERY_CHECK_INTERVAL) should be every minute or
// so. It takes a little time, which could affect snap-and-log interval
// accuracy.
//#define ENABLE_BATTERY_CHECK

#if defined(ENABLE_BATTERY_CHECK)
#define BATTERY_CHECK_INTERVAL  60000 // ms
#endif

#define BATTERY_ERROR_PERCENT   10.0
#define BATTERY_WARN_PERCENT    20.0

// Optional. Define to enable usage tracking. This enables updates to
// counters and uptime for the laser, camera, and device as a whole.
// It also enables periodic updates of a usage stats file on the SD card.
// The values can be used to track usage and uptime for a particular
// battery size and keep track of images recorded to a camera's SD card.
// The counter and uptime updates and the periodic file update (see
// USAGE_FILE_UPDATE_INTERVAL_EVENTS) take a little time, which could affect
// snap-and-log interval accuracy.
//#define ENABLE_USAGE_TRACKING

#if defined(ENABLE_USAGE_TRACKING)
#define USAGE_FILE_UPDATE_INTERVAL_EVENTS 60 // events

typedef struct Usage
{
    // Persistent usage counters and uptime. These are saved to the
    // usage tracking file periodically.
    uint32_t numberOfBoots;
    uint32_t numberOfCameraBoots;
    uint32_t numberOfLaserBoots;
    uint32_t numberOfEventsLogged;
    uint32_t numberOfImagesSnapped;
    uint32_t controllerUptimeSeconds;
    uint32_t cameraUptimeSeconds;
    uint32_t laserUptimeSeconds;

    // Time stamps as seconds since boot. Used to calculate when
    // to update the tracking file.
    uint32_t recentUpdateTime;
} Usage;

extern Usage usage;
#endif


//----------------------------------------------------------------------
// Default settings.
//----------------------------------------------------------------------
#define DEFAULT_FRAME_INTERVAL   1000 // ms
#define DEFAULT_BURST_SIZE       1
#define DEFAULT_LASER_CONTINUOUS false


//----------------------------------------------------------------------
// Intervals and limits.
//----------------------------------------------------------------------
// Shortest frame interval.
//   There are delays built into several of the steps involved in snapping
//   a photo and writing a log file entry. Benchmarking finds these to be
//   around 200 ms. This determines the fastest log time.
#define MINIMUM_FRAME_INTERVAL 200  // ms


//----------------------------------------------------------------------
// Status values.
//----------------------------------------------------------------------
// Hardware status used by getHardwareStatus().
#define HARDWARE_OFF      0
#define HARDWARE_BOOTING  1
#define HARDWARE_ERRORS   2
#define HARDWARE_WARNINGS 3
#define HARDWARE_READY    4

// Software status used by getSoftwareStatus().
#define SOFTWARE_OFF      0
#define SOFTWARE_BOOTING  1
#define SOFTWARE_ERRORS   2
#define SOFTWARE_READY    3
#define SOFTWARE_RUNNING  4

// Camera status used by getCameraStatus().
#define CAMERA_OFF        0
#define CAMERA_BOOTING    1
#define CAMERA_READY      2
#define CAMERA_SHOOTING   3


//----------------------------------------------------------------------
// Forward define functions available to all classes.
//----------------------------------------------------------------------
extern void reset( );

extern uint8_t getHardwareStatus( );
extern void setHardwareStatus( const uint8_t );

extern uint8_t getSoftwareStatus( );
extern void setSoftwareStatus( const uint8_t );

extern uint8_t getCameraStatus( );
extern void setCameraStatus( const uint8_t );

extern bool isLaserContinuous( );
extern bool setLaserContinuous( const bool );

extern uint8_t getBurstSize( );
extern bool setBurstSize( const uint8_t );

extern bool startRunning( );
extern bool stopRunning( );

extern bool snapAndLog( const uint8_t );
extern uint32_t getFrameInterval( );
extern bool setFrameInterval( const uint32_t );

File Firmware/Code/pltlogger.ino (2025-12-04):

/**
 * Pelagic Laser Tomographer (PLT) spatial logger.
 *
 * Developed by the Scripps Institution of Oceanography and the
 * San Diego Supercomputer Center at the University of California at
 * San Diego.
 *
 * The PLT device combines a laser to illuminate pelagic particulate,
 * and a digital camera with intensifier to photograph that particulate
 * at regular time intervals as the device is lowered through a water column.
 * Additional sensors track pressure, temperature, and orientation, and
 * LEDs report basic device status. The device is controlled by an Arduino
 * microcontroller with an SD card used to log the time and sensor data at
 * which each photograph is taken. The camera has its own SD card to store
 * images. A USB serial port on the microcontroller supports a set of basic
 * commands to query the device's status and adjust settings.
 *
 * This software, when loaded onto the microcontroller, initializes the
 * device, provides serial port commands, and runs the camera, laser,
 * LEDs, and logging.
 *
 * See HARDWARE.txt for hardware requirements.
 * See LIBRARIES.txt for software library requirements.
 * See CHANGES.txt for a change log.
 * See TODO.txt for a to-do list.
 */
#include <Arduino.h>
#include "pltlogger.h"

#include "pins.h"       // Device pins.
#include "Battery.h"    // Camera and intensifier battery.
#include "Camera.h"     // Camera and intensifier.
#include "Clock.h"      // Real time clock.
#include "FileSystem.h" // SDCard file system.
#include "Laser.h"      // Laser.
#include "Lights.h"     // Light (LEDs).
#include "Sensors.h"    // Inertial, pressure, and temperature sensors.
#include "Switches.h"   // Switches.
#include "Commands.h"   // Serial port commands.


//----------------------------------------------------------------------
// Globals.
//----------------------------------------------------------------------
// Settings.
bool laserContinuous   = DEFAULT_LASER_CONTINUOUS;
uint8_t burstSize      = DEFAULT_BURST_SIZE;
uint32_t frameInterval = DEFAULT_FRAME_INTERVAL;

// Current state.
uint8_t hardwareStatus   = HARDWARE_OFF;
uint8_t softwareStatus   = SOFTWARE_OFF;
uint8_t cameraStatus     = CAMERA_OFF;
bool batteriesPresent    = false;
uint32_t previousLogTime = 0;

#if defined(ENABLE_BATTERY_CHECK)
// Battery checking state.
#define BATTERY_OK       0
#define BATTERY_LOW      1
#define BATTERY_CRITICAL 2
uint32_t previousBatteryCheckTime = 0;
uint8_t mainBatteryState = BATTERY_OK;
uint8_t controllerBatteryState = BATTERY_OK;
#endif

#if defined(ENABLE_USAGE_TRACKING)
// Usage tracking.
Usage usage;
#endif





//----------------------------------------------------------------------
// Settings.
//----------------------------------------------------------------------
/**
 * Returns the current burst size.
 *
 * The burst size is the number of images to shoot on each snap.
 *
 * @return
 *   Returns the size.
 *
 * @see setBurstSize()
 */
uint8_t getBurstSize( )
{
    return burstSize;
}

/**
 * Returns the current frame interval.
 *
 * @return
 *   Returns the frame interval, in ms.
 *
 * @see setFrameInterval()
 * @see snapAndLog()
 */
uint32_t getFrameInterval( )
{
    return frameInterval;
}

/**
 * Returns true if the laser should be on throughout a run.
 *
 * @return
 *   Returns true if continuous laser.
 *
 * @see setLaserContinuous()
 */
bool isLaserContinuous( )
{
    return laserContinuous;
}

/**
 * Sets the current burst size.
 *
 * The burst size is the number of images to shoot on each snap.
 *
 * @param[in] nImages
 *   Sets the size.
 *
 * @return
 *   Returns true if the change is accepted.
 *
 * @see getBurstSize()
 * @see FileSystem::saveSettings()
 */
bool setBurstSize( const uint8_t nImages )
{
    if ( nImages == burstSize )
        return true; // No change.

    if ( nImages == 0 )
        burstSize = DEFAULT_BURST_SIZE;
    else
        burstSize = nImages;
    FileSystem::saveSettings( frameInterval, laserContinuous, burstSize );
    return true;
}

/**
 * Sets the current frame interval.
 *
 * @param[in] interval
 *   The new frame interval, in ms.
 *
 * @return
 *   Returns true if the change is accepted.
 *
 * @see getFrameInterval()
 * @see snapAndLog()
 * @see FileSystem::saveSettings()
 */
bool setFrameInterval( const uint32_t interval )
{
    if ( interval == frameInterval )
        return true; // No change.

    if ( interval == 0 )
        frameInterval = DEFAULT_FRAME_INTERVAL;
    else if ( interval < MINIMUM_FRAME_INTERVAL )
        return false; // Too small.
    else
        frameInterval = interval;
    FileSystem::saveSettings( frameInterval, laserContinuous, burstSize );
    return true;
}

/**
 * Sets whether the laser should be on continuously or per shoot.
 *
 * @param[in] onOff
 *   Sets whether the laser should be on continuously (true).
 *
 * @return
 *   Returns true if the change is accepted.
 *
 * @see isLaserContinuous()
 * @see FileSystem::saveSettings()
 */
bool setLaserContinuous( const bool onOff )
{
    if ( onOff == laserContinuous )
        return true; // No change.
    laserContinuous = onOff;
    FileSystem::saveSettings( frameInterval, laserContinuous, burstSize );
    return true;
}





//----------------------------------------------------------------------
// Status.
//----------------------------------------------------------------------
/**
 * Returns the camera status.
 *
 * @return
 *   Returns the status.
 *
 * @see setCameraStatus()
 */
uint8_t getCameraStatus( )
{
    return cameraStatus;
}

/**
 * Returns the hardware status.
 *
 * @return
 *   Returns the status.
 *
 * @see setHardwareStatus()
 */
uint8_t getHardwareStatus( )
{
    return hardwareStatus;
}

/**
 * Returns the software status.
 *
 * @return
 *   Returns the status.
 *
 * @see setSoftwareStatus()
 * @see startRunning()
 * @see stopRunning()
 */
uint8_t getSoftwareStatus( )
{
    return softwareStatus;
}

/**
 * Sets the camera status.
 *
 * @param[in] status
 *   The camera status.
 *
 * @see getCameraStatus()
 */
void setCameraStatus( const uint8_t status )
{
    cameraStatus = status;
    Lights::setLightsForStatus( );
}

/**
 * Sets the hardware status.
 *
 * @param[in] status
 *   The hardware status.
 *
 * @see getHardwareStatus()
 */
void setHardwareStatus( const uint8_t status )
{
    hardwareStatus = status;
    Lights::setLightsForStatus( );
}

/**
 * Sets the software status.
 *
 * @param[in] status
 *   The software status.
 *
 * @see getSoftwareStatus()
 * @see startRunning()
 * @see stopRunning()
 */
void setSoftwareStatus( const uint8_t status )
{
    softwareStatus = status;
    Lights::setLightsForStatus( );
}





//----------------------------------------------------------------------
// Reset.
//----------------------------------------------------------------------
#if defined(ENABLE_USAGE_TRACKING)
/**
 * Resets usage tracking.
 *
 * All counters and uptimes are set to zero.
 *
 * @see FileSystem::loadUsage()
 * @see FileSystem::saveUsage()
 */
void resetUsage( )
{
    // Reset all counters.
    usage.numberOfBoots = 0;
    usage.numberOfCameraBoots = 0;
    usage.numberOfLaserBoots = 0;
    usage.numberOfEventsLogged = 0;
    usage.numberOfImagesSnapped = 0;

    // Reset all uptimes.
    usage.controllerUptimeSeconds = 0;
    usage.cameraUptimeSeconds = 0;
    usage.laserUptimeSeconds = 0;

    // Reset the reference timestamps.
    usage.recentUpdateTime = millis( ) / 1000;
}
#endif

/**
 * Resets settings and usage tracking.
 *
 * @see resetUsage()
 */
void reset( )
{
    // Stop running. If running, this should turn off the laser and
    // camera, close the data log, and reset the lights.
    if ( getSoftwareStatus( ) == SOFTWARE_RUNNING )
        stopRunning( );
    else
        Serial.print( "Stopped.\r\n" );

    Serial.print( "Device:\r\n" );
    FileSystem::closeDataLog( );
    Serial.print( "  Data log closed.\r\n");

    Laser::setPower( false );
    Serial.print( "  Laser off.\r\n");

    Camera::setPower( false, true );
    Serial.print( "  Camera and intensifier off.\r\n");

    Lights::reset( );
    Serial.print( "  Lights reset.\r\n");

    Serial.print( "Settings:\r\n" );
    setBurstSize( DEFAULT_BURST_SIZE );
    Serial.printf( "  Burst size reset to %d.\r\n", getBurstSize( ) );

    setFrameInterval( DEFAULT_FRAME_INTERVAL );
    Serial.printf( "  Image interval reset to %ld ms.\r\n", getFrameInterval( ) );

    setLaserContinuous( DEFAULT_LASER_CONTINUOUS );
    Serial.printf( "  Laser reset to %s.\r\n",
        isLaserContinuous( ) ? "continuous" : "normal" );

#if defined(ENABLE_USAGE_TRACKING)
    Serial.print( "Usage tracking reset.\r\n" );
    resetUsage( );
    FileSystem::saveUsage( usage );
#endif

    FileSystem::saveSettings( frameInterval, laserContinuous, burstSize );
}





//----------------------------------------------------------------------
// Run, snap, and log.
//----------------------------------------------------------------------
/**
 * Snaps an image, reads sensors, and adds a data log entry.
 *
 * If the laser mode is not continuous, the laser is turned on before
 * an image is captured, and off afterwards.
 *
 * The camera is triggered and sensors read, then added to the data log.
 *
 * @param[in] nImages
 *   The number of images in a burst.
 *
 * @return
 *   Returns true on success, false on failure. On failure, error
 *   messages have already been printed.
 *
 * @see getFrameInterval()
 * @see setFrameInterval()
 * @see startRunning()
 * @see stopRunning()
 */
bool snapAndLog( const uint8_t nImages )
{
    float pressure = 0.0;
    float depth = 0.0;
    float waterTemperature = 0.0;
    float deviceTemperature = 0.0;
    float accel[3];
    float mag[3];
    float gyro[3];
    bool status = true;

#ifdef DEBUG_BENCHMARK_SNAP_AND_LOG
    uint32_t previousTime = millis( );
    uint32_t nextTime = previousTime;
    uint32_t powerOnTime = 0;
    uint32_t powerOffTime = 0;
    uint32_t shutterTime = 0;
    uint32_t sensorTime = 0;
    uint32_t logTime = 0;
#endif

    //
    // Camera, intensifier, and laser power up (as needed).
    //
    // Insure the camera and intensifier power is on.
    // - When this function is called during a run, the camera and intensifier
    //   are already on.
    // - When this function is called outside of a run to snap just once, the
    //   camera and intensifier are not already on and must be turned on now.
    const bool initialCameraPower = Camera::isPowerOn( );
    if ( !initialCameraPower )
    {
        setCameraStatus( CAMERA_BOOTING );
        Camera::setPower( true );
        setCameraStatus( CAMERA_READY );
    }

    // Insure the laser is on.
    const bool initialLaserPower = Laser::isPowerOn( );
    if ( !initialLaserPower )
        Laser::setPower( true );

#ifdef DEBUG_BENCHMARK_SNAP_AND_LOG
    powerOnTime = (nextTime = millis()) - previousTime;
    previousTime = nextTime;
#endif

    //
    // Capture.
    //
    // Snap images and update usage.
    setCameraStatus( CAMERA_SHOOTING );
    Camera::snap( nImages );
#ifdef DEBUG_BENCHMARK_SNAP_AND_LOG
    shutterTime = (nextTime = millis()) - previousTime;
    previousTime = nextTime;
#endif

    //
    // Camera, intensifier, and laser power down (as needed).
    //
    // Turn off the laser, if it was originally off.
    if ( !initialLaserPower )
        Laser::setPower( false );

    // Turn off the camera and intensifier, if it was originally off.
    if ( !initialCameraPower )
    {
        Camera::setPower( false );
        setCameraStatus( CAMERA_OFF );
    }
    else
        setCameraStatus( CAMERA_READY );

#ifdef DEBUG_BENCHMARK_SNAP_AND_LOG
    powerOffTime = (nextTime = millis()) - previousTime;
    previousTime = nextTime;
#endif


#if defined(ENABLE_USAGE_TRACKING)
    //
    // Update usage tracking in memory.
    //
    usage.numberOfImagesSnapped += nImages;
    ++usage.numberOfEventsLogged;
    const uint32_t ut = millis( ) / 1000;
    usage.controllerUptimeSeconds += (ut - usage.recentUpdateTime);
    usage.recentUpdateTime = ut;
#endif


    //
    // Log.
    //
    // If there is a data log (and there is while running automaticaly),
    // then read the sensors and add a data log entry.
    //
    // If it is time to update the usage tracking file, get the most recent
    // values and save them.
    if ( FileSystem::isDataLogOpen( ) )
    {
        // Read the sensors.
        Sensors::getWaterPressure( pressure, depth );
        Sensors::getWaterTemperature( waterTemperature );
        Sensors::getInertia( accel, mag, gyro, deviceTemperature );
#ifdef DEBUG_BENCHMARK_SNAP_AND_LOG
        sensorTime = (nextTime = millis()) - previousTime;
        previousTime = nextTime;
#endif

        // Write to the data log.
        if ( !FileSystem::writeDataLog(
            Clock::nowString( ),
            Clock::nowMillisOffset( ),
            pressure,
            depth,
            waterTemperature,
            deviceTemperature,
            accel,
            mag,
            gyro ) )
        {
            // Log file write error. Possible failures:
            // - The SD card is not inserted.
            // - The SD card is full.
            // - The file has reached the 4GB max size for FAT.
            // - A hardware error has occurred.
            // - An internal SdFat error has occurred.
            Serial.print( "Cannot write to data log file.\r\n" );
            FileSystem::printErrorMessage( );

            if ( FileSystem::isCardPresent( ) )
            {
                // Try to log a status message. This will fail silently if the
                // SD card is full.
                FileSystem::writeStatus( "Cannot write to data log file" );
                FileSystem::writeStatus( FileSystem::getErrorMessage( ) );
            }
            status = false;
        }
#if defined(ENABLE_USAGE_TRACKING)
        else
        {
            // Update the usage tracking file.
            if ( USAGE_FILE_UPDATE_INTERVAL_EVENTS <= 1 ||
                (usage.numberOfEventsLogged % USAGE_FILE_UPDATE_INTERVAL_EVENTS) == 0 )
            {
                // Copy out the current Camera and Laser counters.
                usage.numberOfCameraBoots = Camera::getNumberOfPowerOns( );
                usage.cameraUptimeSeconds = Camera::getUptimeSeconds( );
                usage.numberOfLaserBoots  = Laser::getNumberOfPowerOns( );
                usage.laserUptimeSeconds  = Laser::getUptimeSeconds( );
                FileSystem::saveUsage( usage );
            }
        }
#endif

#ifdef DEBUG_BENCHMARK_SNAP_AND_LOG
        logTime = (nextTime = millis()) - previousTime;
        previousTime = nextTime;
#endif
    }

#ifdef DEBUG_BENCHMARK_SNAP_AND_LOG
    Serial.printf( "On %ld |Image %ld |Off %ld |Sensor %ld |Log %ld|= %ld\r\n",
        powerOnTime,
        shutterTime,
        powerOffTime,
        sensorTime,
        logTime,
        (powerOnTime + shutterTime + powerOffTime + sensorTime + logTime) );
#endif
    return status;
}

/**
 * Starts snapping images and logging sensor readings.
 *
 * If the current state is not READY_STATE, no action is taken.
 *
 * The camera and intensifier power is turned on. The lights are set
 * to show the device is running. A new log file is created. A starting
 * photo and sensor reading is logged and the current time noted for
 * tracking frame intervals.
 *
 * There are several delays built in to these steps, so this function
 * does not return quickly.
 *
 * @return
 *   Returns true on success, false on failure. On failure, error
 *   messages have already been printed.
 *
 * @see getCameraStatus()
 * @see getHardwareStatus()
 * @see getSoftwareStatus()
 * @see snapAndLog()
 * @see stopRunning()
 */
bool startRunning( )
{
    if ( getSoftwareStatus( ) != SOFTWARE_READY )
        return false;

    Serial.printf( "Starting...\r\n" );
    if ( !FileSystem::newDataLog( ) )
    {
        // Fail to create a new log. Possible failures:
        // - The SD card is not inserted.
        // - The SD card is full.
        // - The maximum number of files in a FAT directory has been reached.
        // - The maximum number of log files has been reached.
        //
        // FileSystem error codes have been set, so print an error message.
        Serial.print( "Cannot create new data log file.\r\n" );
        FileSystem::printErrorMessage( );

        if ( !FileSystem::isCardPresent( ) )
        {
            // Fail with missing SD card. There is no way to log a status
            // message. Go to an ERROR run state.
            setHardwareStatus( HARDWARE_ERRORS );
            setSoftwareStatus( SOFTWARE_ERRORS );
        }
        else
        {
            // Try to log a status message. This will fail silently if the
            // SD card is full.
            FileSystem::writeStatus( "** Cannot create new data log file" );
            FileSystem::writeStatus( FileSystem::getErrorMessage( ) );
        }
        return false;
    }

    // Announce and add a status message.
    char buf[1025];
    const char*const name = FileSystem::getDataLogFilename( );
    Serial.print( "Camera and intensifier powering up...\r\n" );
    sprintf( buf, "Start running. Logging to %s.", name );
    FileSystem::writeStatus( buf );

    // Turn on the camera. Leave it on while running.
    setSoftwareStatus( SOFTWARE_RUNNING );
    setCameraStatus( CAMERA_BOOTING );
    Camera::setPower( true );
    setCameraStatus( CAMERA_READY );
    Serial.printf( "Running. Logging to %s.\r\n", name );

    // If the laser mode is continuous, turn on the laser and leave it on.
    if ( isLaserContinuous( ) )
        Laser::setPower( true );

    // Initial shot.
    if ( !snapAndLog( burstSize ) )
    {
        // Write error on the log. Possible failures:
        // - The SD card is not inserted.
        // - The SD card is full.
        // - The file has reached the 4GB max size for FAT.
        // - A hardware error has occurred.
        // - An internal SdFat error has occurred.
        Camera::setPower( false );
        Laser::setPower( false );
        setCameraStatus( CAMERA_OFF );
        setSoftwareStatus( SOFTWARE_ERRORS );

        if ( !FileSystem::isCardPresent( ) )
        {
            Serial.print( "Cannot start running due to critical problems.\r\n" );
            setHardwareStatus( HARDWARE_ERRORS );
        }
        return false;
    }

    previousLogTime = millis( );
    Serial.println( );
    return true;
}
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
void loop( )
{
    uint32_t currentTime = millis( );

    // For any run state, check for and run serial port commands. This
    // allows status checks and file downloads even when there are
    // hardware errors.
    //Commands::processCommands( );

#if defined(ENABLE_BATTERY_CHECK)
    // Check batteries periodically. If a battery goes low or critically
    // low, the hardware and software status may change and snap and log
    // may stop.
    if ( (currentTime - previousBatteryCheckTime) >= BATTERY_CHECK_INTERVAL )
    {
        previousBatteryCheckTime = currentTime;
        checkBatteries( );
    }
#endif

    // Updates switch state.
    Switches::update( );

    // When in an error state, parts of the device are not working and there
    // is no further work that can be done. Ignore any switches or sensors.
    switch ( getSoftwareStatus( ) )
    {
        default:
        case SOFTWARE_OFF:
        case SOFTWARE_BOOTING:
            // Not possible.
            return;

        case SOFTWARE_ERRORS:
            // When there are software errors, we can't keep running.
            return;

        case SOFTWARE_READY:
        case SOFTWARE_RUNNING:
            break;
    }

    // If the start/stop switch is pressed, toggle between RUNNING and
    // READY states.
    if ( Switches::isStartStopPressed( ) )
    {
        if ( getSoftwareStatus( ) == SOFTWARE_RUNNING )
            stopRunning( );
        else
        {
            // This automatically takes the first photo.
            startRunning( );
        }
        return;
    }

    // While running, check if enough time has elapsed since the last
    // snapshot and log entry.  If so, snap a picture and log sensors.
    if ( getSoftwareStatus( ) == SOFTWARE_RUNNING )
    {
        currentTime = millis( );
        if ( (currentTime - previousLogTime) >= frameInterval )
        {
            previousLogTime = currentTime;
            snapAndLog( getBurstSize( ) );
        }
    }
}





/**
 * Serial event handler.
 *
 * This function is automatically called by the Arduino run-time after each
 * call to loop(), if there is data available on the serial input.
 *
 * Note that on some Arduino's, the function should be serialEvent().
 */
void serialEventRun( )
{
    Commands::handleSerialInput( );
}

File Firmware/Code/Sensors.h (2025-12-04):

#pragma once
#include <stdint.h>
#include <stdbool.h>
#include <Adafruit_LSM9DS1.h>   // Gyroscope, Accelerometer, & Magnetometer
#include <MS5837.h>             // Pressure, depth, and temperature sensor
#include <TSYS01.h>             // Temperature sensor

#include "pltlogger.h"


/**
 * Manages device sensors.
 *
 * Sensors include:
 *
 * - An LSM9DS1 9-axis iNEMO inertial module (IMU). The sensor incorporates
 *   a 3D magnetometer, 3D accelerometer, and 3D gyroscope. The module also
 *   reports the internal device temperature.
 *
 * - A MS5837 30 bar digital pressure sensor. The sensor reports water
 *   pressure and depth to a 2mm resolution. An included low-resolution
 *   water temperature sensor is not used.
 *
 * - A TSYS01 digital temperature sensor. The high-resolution sensor reports
 *   water temperature between -5 and 50 C, +/- 0.1C.
 *
 * @see https://www.st.com/en/mems-and-sensors/lsm9ds1.html
 * @see https://www.st.com/resource/en/datasheet/lsm9ds1.pdf
 * @see https://www.mouser.com/new/measurement-specialties/te-ms5837-30ba/
 * @see https://www.te.com/usa-en/product-CAT-BLPS0017.html
 * @see https://www.te.com/commerce/DocumentDelivery/DDEController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
 * @see https://www.mouser.com/ProductDetail/Measurement-Specialties/TSYS01/?qs=X3dlXJsz9DAvF3tElFUMhA%3D%3D
 */
class Sensors
{
private:
    Sensors( ) = delete;
    Sensors( const Sensors& ) = delete;
    Sensors& operator=( const Sensors& ) = delete;


//----------------------------------------------------------------------
// Constants.
//----------------------------------------------------------------------
public:
    // Water density for fresh water (997 kg/m^3 for fresh water).
    static constexpr float FRESHWATER = 997.0;

    // Water density for sea water (1029 kg/m^3 for sea water).
    static constexpr float SALTWATER = 1029.0;

    // Celsius -274 = 0 Kelvin = lowest possible temperature.
    static constexpr float BAD_WATER_TEMPERATURE = -274.0;

    // Initialization state.
    static const uint8_t INERTIA_INITIALIZED     = 0x01;
    static const uint8_t PRESSURE_INITIALIZED    = 0x02;
    static const uint8_t TEMPERATURE_INITIALIZED = 0x04;
    static const uint8_t ALL_INITIALIZED =
        (INERTIA_INITIALIZED | PRESSURE_INITIALIZED | TEMPERATURE_INITIALIZED);


//----------------------------------------------------------------------
// Fields.
//----------------------------------------------------------------------
private:
    static Adafruit_LSM9DS1 inertiaSensor;
    static MS5837 pressureSensor;
    static TSYS01 temperatureSensor;
    static uint8_t initialized;
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
